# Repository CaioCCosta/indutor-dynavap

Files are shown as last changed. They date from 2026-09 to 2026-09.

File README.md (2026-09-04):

# Indutor DIY para Dynavap

**v1 fechada (set/2026).** Aquecedor de mesa **12 V 10 A** na tomada, caixa 3D pronta para imprimir (relevo AMS ou cavas + cola). Pack de 18650/21700 fica para uma **v2**.

Este kit junta o que Reddit (`r/inductionheaters`), FuckCombustion, VapOven, Thingiverse/Printables e aparelhos comerciais (Wand, YLL 3.0) acertam — e descarta o que queima módulo ou deixa o clique inconsistente.

| Documento | Conteúdo |
|---|---|
| [BOM e fiação](BOM_E_FIACAO.md) | Lista de peças no Brasil, pinos do Nano, diagrama |
| [**Caixa 3D v1**](caixa-3d/README.md) | [Lisa](caixa-3d/print/v1-lisa/), [relevo AMS](caixa-3d/print/v1/) ou [cavas](caixa-3d/print/v1-cavas/) |
| [Lista Mercado Livre](LISTA_COMPRAS_MERCADOLIVRE.md) | Buscas + anúncios + frete CEP 72120-250 |
| [Lista Shopee](LISTA_COMPRAS_SHOPEE.md) | Mesmo modelo de checklist na Shopee |
| [**Lista híbrida**](LISTA_COMPRAS_HIBRIDA.md) | **Melhor custo total — modelo, preço e frete por pedido** |
| [Firmware](firmware/indutor_dynavap.ino) | Botão, timeout 60 s, pulso lento, corte a 60 °C |
| [Afinação e segurança](AFINACAO_E_SEGURANCA.md) | Bobina 16 mm, alvo 60–70 W, checklist |
| [**Maquetes 3D**](maquetes/viewer.html) | Visualizador precisão v1.1 · [layout interno](maquetes/LAYOUT_INTERNO.md) · [montagem](maquetes/MONTAGEM.md) |

---

## Como funciona

O módulo **ZVS** (oscilador Royer, ~20–100 kHz) alimenta uma bobina. O campo magnético induz correntes de Foucault no cap de aço ou titânio; o metal esquenta de dentro para fora. O clique bimetálico continua sendo o termômetro. Vidro, cerâmica e plástico não aquecem.

O G3 de vidro **não** deve ir em indução (orientação DynaVap).

O que realmente muda o clique:

1. Diâmetro e número de espiras da bobina
2. Profundidade de inserção — o ponto mais quente é o **centro** da bobina
3. Potência efetiva — ~**60–70 W** dá extração uniforme; potência máxima deixa o clique rápido demais e inconsistente entre caps
4. Tempo de exposição — o IH não tem “temperatura”; ele só aquece enquanto estiver ligado

```mermaid
flowchart LR
  PSU["Fonte 12V 10A"] --> Fuse["Fusivel 10A"]
  Fuse --> MOSFET["MOSFET 15-30A"]
  MCU["Arduino Nano"] -->|"TRIG lento"| MOSFET
  MOSFET --> ZVS["Modulo ZVS 5-12V"]
  ZVS --> Coil["Bobina 16mm"]
  Coil --> Cap["Cap Dynavap"]
  Stop["Trava ajustavel"] --> Cap
```

---

## Comparação: comprar vs montar

### Aparelhos prontos

| Modelo | Tipo | Preço aprox. | O que acerta | O que falha |
|---|---|---|---|---|
| **Ispire Wand** | Portátil + dock | USD 115–180 | Adaptador Dynavap, auto/manual, 2×18650 | Auto-shutoff irregular; profundidade mal documentada; caro no BR |
| **YLL 3.0** | Portátil | USD 119–129 | **30–100 W**, profundidade ajustável, vidro trocável, timer 10–60 s, luz, 2×21700 | Baterias muitas vezes à parte; mais peça para copiar do que para reinventar |
| **VapOven** (pronto / kit) | Mesa ou bateria | £45–80 kit | Melhor documentação aberta; fonte de parede **12 V 10 A** | Frete UK; kit de bateria exige células high-drain |
| Orion / Portside Mini | Portátil clássico | nicho / descontinuado | Formato de bolso, clique previsível | Bateria única; variação de bobina entre unidades |
| Sense (Mad Heaters) | Portátil premium | alto | Corta no clique | Preço e estoque |
| Koil Boi / Caldron / VapHotBox / DynaBox | mesa ou USB-C | EUR 80–150 | “Liga e usa” | Menos ajuste que YLL; DIY ganha em custo |

**Comprar** Wand ou YLL 3.0 se a prioridade é usar amanhã. **Montar** este desktop se a prioridade é aprender e gastar ~R$ 150–280.

### Planos grátis e comunidade

| Fonte | O que pegar | O que não copiar |
|---|---|---|
| [VapOven library](https://vapoven.com/build-your-own-dynavap-induction-heater/) | MOSFET no positivo, não cortar o fio da bobina, Arduino com pulso e corte 60 °C | Lista antiga de fonte “12 V qualquer”; o produto deles usa **10 A** |
| [r/inductionheaters](https://www.reddit.com/r/inductionheaters/) + fiação jojo04201 | Arquitetura canônica: ZVS 5–12 V + MOSFET + botão momentâneo | LiPo de drone; comutar 10 A no botão barato |
| [jnico / Thingiverse](https://www.thingiverse.com/thing:4171627) | Caixa 3D, tubo de vidro, cortiça como trava | Fonte 6 A — justa demais |
| [acsdog / Printables](https://www.printables.com/model/1067938-dynavap-induction-heater-box-with-pwm) | Rebobinar 16 AWG no diâmetro do vidro, gabarito de enrolar | PWM de kHz no ZVS |
| [PULSE / Hackster](https://www.hackster.io/wiskey_tango_foxtrot/pulse-induction-heater-dc97ee) | Ciclos on/off de segundos (slowCook) | Tempos fixos no código; melhor um potenciómetro |
| FuckCombustion (física do IH) | Alvo **60–70 W**, banda quente no centro da bobina | Perseguir o clique mais rápido possível |

---

## Conflitos resolvidos

1. **Fonte 6 A vs 10 A.** O ZVS 120 W puxa ~10 A em 12 V. Fonte 6 A cai de tensão; abaixo de 12 V os dois MOSFETs do ZVS conduzem juntos e queimam. **Usar 12 V 10 A (folga: 12 A).**
2. **PWM no ZVS.** PWM de centenas de Hz / kHz impede o oscilador de arrancar. Potência = ligar/desligar o MOSFET em períodos de **100–500 ms**. Não usar `analogWrite` rápido.
3. **Bateria vs tomada.** 3S 18650 funciona, mas é o maior risco. LiPo de drone está fora. BMS de 10 A das listas antigas é apertado. **v1 na tomada.**
4. **Bobina de estoque vs rebobinada.** A bobina do módulo vem com ~23–28 mm de diâmetro interno — frouxa para o cap. Apertar sem cortar (~5 espiras / 16 mm) **ou** rebobinar 16 AWG, 8–10 espiras no tubo.
5. **Potência máxima vs sabor.** Clique < 3 s costuma super-extrair. FC recomenda 60–70 W para clique consistente entre caps.

---

## Arquitetura desta v1 (melhor de cada)

| Origem | O que entrou |
|---|---|
| VapOven | ZVS 5–12 V, MOSFET, botão momentâneo, LED na câmara, tubo 16 mm, O-ring, cavilha |
| YLL 3.0 | Potência ajustável, profundidade mecânica, **timeout 60 s**, vidro trocável, luz |
| FuckCombustion | Calibrar para ~60–70 W |
| Printables | Bobina justa no vidro |
| Thingiverse | Caixa 3D e trava de altura |
| Arduino VapOven | Pulso lento, corte térmico ~60 °C, LED de status |

**Fora da v1:** 18650/21700, BMS, LiPo, PWM de alta frequência, ZVS 12–48 V / 1800 W (é para fundir metal).

Firmware: botão pressionado aquece, soltou para; timeout 60 s se o botão travar; duty pelo potenciómetro; não dispara com dissipador ≥ 60 °C. O clique do cap é o feedback — não há malha IR nesta versão.

Próximo passo: imprimir uma das variantes em [`caixa-3d/print/`](caixa-3d/print/README.md), comprar pela [**lista híbrida**](LISTA_COMPRAS_HIBRIDA.md) (ou [ML](LISTA_COMPRAS_MERCADOLIVRE.md) / [Shopee](LISTA_COMPRAS_SHOPEE.md)), ligar conforme [BOM](BOM_E_FIACAO.md), gravar o [firmware](firmware/indutor_dynavap.ino), depois [afinar a bobina](AFINACAO_E_SEGURANCA.md).

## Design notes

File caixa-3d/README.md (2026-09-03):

# Caixa 3D — indutor Dynavap (A14) **v1 fechada**

**v1 fechada (set/2026).** OpenSCAD em `caixa-3d/`, [dimensions.json](../maquetes/dimensions.json) **v1.0** (92×58×65 mm + tampa 8 mm), ímã Ø12×3 em **X=−14**. Mesma caixa, **duas variantes oficiais** de acabamento tribal.

| Variante | Pasta | Uso |
|---|---|---|
| **Lisa** | [`print/v1-lisa/`](print/v1-lisa/) | Sem tribal; corpo + pads |
| **Relevo AMS** | [`print/v1/`](print/v1/) | Duas cores no Orca (Assemble) |
| **Cavas + cola** | [`print/v1-cavas/`](print/v1-cavas/) | Casca cavada 0,6 mm; inserts 0,5 mm colados |

Não misture os dois packs no mesmo Assemble.

## Arquivos — relevo AMS

Pasta: [`print/v1/`](print/v1/)

| Arquivo | O que é | Filamento Orca/Bambu AMS |
|---|---|---|
| [`corpo_cor1.stl`](print/v1/corpo_cor1.stl) | Casca do corpo + 4 pads | **1** PETG escuro |
| [`corpo_cor2.stl`](print/v1/corpo_cor2.stl) | Relevo tribal (5 faces) | **2** PETG claro |
| [`tampa_cor1.stl`](print/v1/tampa_cor1.stl) | Casca da tampa | **1** PETG escuro |
| [`tampa_cor2.stl`](print/v1/tampa_cor2.stl) | Relevo tribal do topo | **2** PETG claro |

Fallback **uma cor / lisa:** preferir [`print/v1-lisa/`](print/v1-lisa/) (`corpo_liso.stl` + `tampa_lisa.stl`). Alternativa unida com relevo: [`stl/box_body.stl`](stl/box_body.stl) · [`stl/box_lid.stl`](stl/box_lid.stl).

### OrcaSlicer / Bambu X1 Carbon

Imprima **corpo e tampa em placas separadas** (ou as duas na cama se couber).

1. **Add** `*_cor1.stl` e `*_cor2.stl` da mesma peça.
2. Selecione os dois → clique direito → **Assemble** (um objeto, duas partes).
3. Parte casca → **Filament 1**; parte relevo → **Filament 2**.
4. Perfil: **PETG**, camada **0,2 mm**, bico **0,4 mm**, infill **15–25 %**, sem suportes.
5. Orientação: corpo **piso no bed**; tampa **face plana no bed** (pocket, collarinho e relevo para cima).
6. O relevo tem **0,8 mm** = **4 camadas** de cor 2. Flush AMS no padrão.

Não use os STL unidos (`box_body.stl` / `box_lid.stl`) se quiser duas cores.

## Arquivos — cavas + cola

Pasta: [`print/v1-cavas/`](print/v1-cavas/) · [LEIA-ME](print/v1-cavas/LEIA-ME.md)

Cava **0,6 mm**; inserts **0,5 mm** deitados (`decais.stl` ou `decal_*.stl`). Imprime casca e tribal em placas **separadas** e cola.

## Gerar / regenerar STL

```powershell
cd caixa-3d
.\export.ps1
```

Pipeline: OpenSCAD gera `*_base.stl` → `assemble_embossed.py` gera `print/v1-lisa/`, `print/v1/` (AMS) e `print/v1-cavas/`.

Requer: [OpenSCAD](https://openscad.org/), Python com `trimesh`, `manifold3d`, `scikit-image`, `Pillow`.

| Arquivo | Função |
|---|---|
| `box_params.scad` | Medidas (corpo, furos, tubo, ímã, EMBOSS_H) |
| `box_body.scad` / `box_lid.scad` | Casca base imprimível |
| `box_emboss.scad` | Referência de layout do relevo (assembly em Python) |
| `decals/vectorize_decals.py` | JPG → STL de relevo 0,8 mm |
| `assemble_embossed.py` | Une base + decals (v1); difference cavas + inserts (`print/v1-cavas`) |
| `export.ps1` | Compila tudo |

## Decals tribais (alto relevo)

| Face | Decal | Arquivo |
|---|---|---|
| Laterais (frente, trás, esq., dir.) | **1** — asa horizontal | `decals/tribal_1_*` |
| Tampa (topo) | **2** — preenche a área livre (sem o bocal); ímã no centro | `decals/tribal_2_*` |
| Base (fundo) | **3** — chama no eixo longo | `decals/tribal_3_*` + **4 pads** 1,0 mm na casca (cor 1) |

- Altura do relevo: **0,8 mm** (`EMBOSS_H`)
- Keepouts: furos do painel, jack, fusível, vents, pocket ímã, collarinho, parafusos M3
- Regenerar só os relevos: `python decals/vectorize_decals.py` depois `python assemble_embossed.py`

### Cavidade do ímã

- Posição: **centro da área livre** da tampa (`X≈−14`), longe do tubo (`X≈28`)
- Pocket: **Ø12,6 × 3,2 mm** (ímã Ø12×3 + folga/cola)
- Fundo fechado — cola cianoacrilato ou epóxi 5 min
- Para ímã **12×6**: em `box_params.scad` defina `MAGNET_H = 6` e reexporte (gera boss local)

## Ímã de descanso (Dynavap upright)

Segura o M7 pelo cap metálico entre sessões. **Não** é a trava de profundidade do tubo (essa é o fundo de vidro).

| Exemplo | Spec | Nota | Link |
|---|---|---|---|
| VapOven Cooling Magnet | **12×3** N52 **diametral** (ou 12×6) | Referência Dynavap | [vapoven.com](https://vapoven.com/product/vapoven-cooling-magnet/) |
| DynaMag oficial | **12,6×1,5** diametral | Cabe no pocket com cola | [dynavap.com](https://www.dynavap.com/products/the-dynamag) |
| MadMag | **14×2** | Mais forte; mude `MAGNET_D=14` | [madheaters](https://madheaters.co.uk/products/madmag) |
| BR (axial) | **12×3 N35** ~1–2,5 kg tração ideal | Sobra p/ ~30 g do M7 | [Polo Magnético](https://www.polomagnetico.com.br/ima-de-neodimio/disco/ima-de-neodimio-12-x-3-mm-n35) · [Lorben](https://www.lorben.com.br/10-pecas-ima-neodimio-12x3mm-disco-pastilha-super-forte) |

**Preferir diametral** (cap centra e fica em pé). Axial funciona no peso, mas tombear é mais fácil. Não aqueça o ímã acima de **~80 °C**.

## Impressão sugerida (OrcaSlicer / X1 Carbon)

| Parâmetro | Valor |
|---|---|
| Material | **PETG** mínimo; **ASA/ABS** melhor perto do tubo |
| Camada | 0,2 mm |
| Preenchimento | 15–25 % |
| Corpo | Base no bed (Z=piso); pads 1 mm nos cantos (cor 1) |
| Tampa | Face plana no bed; pocket, collarinho e relevo para cima |
| Suportes | Desnecessário na cavidade ≤3,2 mm |
| Relevo tribal | Filamento **2**; nozzle **0,4 mm**; pontas finas podem arredondar |
| Parafusos | M3 nos 4 cantos (furos 3,4 mm; posts com piloto Ø2,4) |

## Encaixe com o BOM

Furos do painel (frente → traseira), alinhados à lista A5–A9 / A15:

| Item | Peça | Furo / rasgo |
|---|---|---|
| A7 | Gangorra redonda KCD1-106N | **Ø20,2 mm** |
| A5 | Pot B10K WH148 | **Ø7,6 mm** |
| A6 | Botão momentâneo 19 mm | **Ø19,2 mm** |
| A9 | LED 5 mm (×2) | **Ø5,2 mm** |
| A15 | Jack DC-022 P4 | **Ø8,2 mm** (traseira) |
| A8 | Porta-fusível 5×20 | **Ø13,2 mm** (traseira) |

- Tubo ensaio 16×42 (de 16×100) + cama cerâmica 24×24 sob o fundo
- Bobina + O-ring 15×3 no collarinho
- ZVS + MOSFET + Nano + pot + botão + rocker nos furos do painel
- Ventilação traseira 4×10×4 mm — não feche hermético
- Ímã colado na cavidade da tampa
- Fonte 12 V 10 A **fora** da caixa (só o jack entra)

## Alternativas (legado)

Se quiser partir de um design comunitário e editar:

- [acsdog — Printables](https://www.printables.com/model/1067938-dynavap-induction-heater-box-with-pwm) (domínio público, FreeCAD)
- [jnico — Thingiverse](https://www.thingiverse.com/thing:4171627)

A caixa paramétrica deste repo já inclui o layout v3.2 + ímã; prefira ela.

## Visualizar

[Viewer 3D](../maquetes/viewer.html) · [MONTAGEM.md](../maquetes/MONTAGEM.md)

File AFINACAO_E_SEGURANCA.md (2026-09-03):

# Afinação da bobina e segurança

Alvo desta v1: clique em **5–8 s** com **~60–70 W** (cerca de 5–6 A em 12 V com o cap inserido). Clique abaixo de 3 s costuma super-extrair; acima de 12 s a bobina está frouxa ou o duty está baixo demais.

Firmware e pinos: [indutor_dynavap.ino](firmware/indutor_dynavap.ino) e [BOM_E_FIACAO.md](BOM_E_FIACAO.md). Caixa oficial v1: [lisa](caixa-3d/print/v1-lisa/), [relevo](caixa-3d/print/v1/) ou [cavas](caixa-3d/print/v1-cavas/).

---

## Bobina: duas formas válidas

A bobina de fábrica do ZVS 120 W vem com ~23–28 mm de diâmetro interno. O cap Dynavap fica longe do cobre e o clique atrasa ou fica irregular. **Não corte o fio** se for só remodelar o comprimento original — o tanque LC precisa dessa indutância.

### A) Apertar a bobina original (VapOven)

1. Use o tubo de 16 mm como mandril.
2. Feche para **~5 espiras** justas no vidro.
3. O restante do fio fica dobrado para o lado, **inteiro**, até os bornes.
4. Soldar a bobina na placa. Bornes de plástico derretem com o uso.

### B) Rebobinar 16 AWG (Printables / acsdog)

1. Fio esmaltado 16 AWG. Raspé as pontas até o cobre aparecer.
2. Enrolar **8–10 espiras** no tubo de 16 mm (ou num gabarito do mesmo diâmetro).
3. Espiras apertadas, sem sobrepor isolamento danificado (curto entre voltas mata o ZVS).
4. Mesmo número de voltas da bobina original se você medi-las antes de desmontar — ponto de partida mais seguro.
5. Soldar na placa.

O tubo de vidro fica **dentro** da bobina. O-ring 15×3 mm fixa o tubo na caixa. O **fundo fechado** do tubo (ensaio 16×100 cortado) é o stop do cap. A cama cerâmica 24×24 fica **sob** o fundo (isola PETG). O ímã Ø12×3 na **tampa** é só descanso upright — não define profundidade.

---

## Profundidade (YLL + FuckCombustion)

O campo é uma banda quente no **centro** das espiras. Mais cap dentro da bobina = mais cobre “vendo” metal = clique mais rápido.

| Objetivo | Ajuste |
|---|---|
| Primeiro teste | Cap **inteiro** na bobina |
| Clique < 3 s | Menos cap no centro / abrir espiras / baixar pot |
| Clique > 12 s | Mais cap na bobina / apertar espiras / subir pot |
| Sabor / terpenos | Um pouco menos fundo, duty menor (pulso) |
| Nuvem | Cap inteiro, duty alto, ainda na faixa 60–70 W |

Marque a posição boa com uma fita no tubo. A repetibilidade é o motivo de existir IH.

---

## Procedimento de afinação

Faça com a caixa aberta, multímetro em série no positivo (escala 10 A DC) se possível, e o interruptor geral à mão.

1. **Bobina no ar, sem cap.** Pulso curto. Corrente ociosa baixa (cerca de 1–2 A nos ZVS bem comportados). Fonte não pode piscar nem cair abaixo de ~11,5 V.
2. **Pot no mínimo** (sentido do sketch = potência cheia). Inserir o Dynavap até o fundo do tubo. Contar até o clique.
3. Alvo **5–8 s**. Anotar corrente com o cap dentro.
4. Potência elétrica ≈ `12 V × corrente`. Ajustar pot e/ou bobina para **~5–6 A (60–72 W)**. Não persiga o 10 A nominais do módulo.
5. Se a fonte entrar em proteção: espiras demais / diâmetro pequeno demais / cap enfiado demais. Abra a bobina ou reduza a penetração do cap.
6. Se o clique não vem: cap de vidro/cerâmica, bobina frouxa, polaridade do MOSFET, ou TRIG invertido (`MOSFET_ACTIVE_HIGH`).
7. Com o TMP36 no dissipador, segure o botão: em ≥ 60 °C o LED status pisca rápido e o ZVS corta. Solte e espere cair de 55 °C. Serial `Ts=0` significa sensor ausente ou leitura absurda — o corte térmico fica desligado até o TMP36 estar no dissipador.
8. Segure 60 s de propósito: o firmware corta (pisca lento). Solte o botão para rearmar.

Módulos ZVS nacionais pedem pausa depois de ~5 min contínuos. O timeout de 60 s cobre o uso real; não use o IH como fogão.

---

## Potenciómetro no firmware

| Posição | Comportamento |
|---|---|
| Quase todo aberto (ADC baixo) | ZVS contínuo enquanto o botão estiver apertado |
| Meio / fechado | Pulso lento, período 500 ms, “on” de ~500 ms até 120 ms |

Isso é o slowCook do VapOven / PULSE do Hackster: o ZVS **arranca e oscila** em cada pulso. PWM de kHz não dá tempo de oscilar e queima MOSFET.

---

## Checklist de segurança

Faça na ordem. Qualquer “não” = não aquece o cap.

- [ ] Fonte é **12 V 10 A** (ou 12 A), não 6 A
- [ ] ZVS é o de **5–12 V / 120 W**, não o de 1800 W
- [ ] Fusível **10 A** no positivo, depois do interruptor, antes do MOSFET
- [ ] MOSFET comuta o **12 V do ZVS**; botão só no D2
- [ ] GND comum: fonte, MOSFET, ZVS, Nano
- [ ] Polaridade da fonte conferida no jack
- [ ] Bobina soldada; isolamento entre espiras intacto; **fio original não cortado** se for o método A
- [ ] Dissipadores do ZVS com ar; caixa não é fechada hermética
- [ ] TMP36 no dissipador, não flutuando no ar da caixa
- [ ] Timeout e corte térmico testados **sem** cap na primeira vez
- [ ] Não usar Dynavap **G3 de vidro** (nem cap de vidro/cerâmica/plástico)
- [ ] Cap sai quente; o vidro isola a **bobina**, não o cap
- [ ] Não deixar o botão preso e sair da sala — o timeout é backup, não babysitter
- [ ] Sem LiPo. v2 de bateria: só 18650/21700 high-drain ≥ 20 A e BMS ≥ 15 A

---

## Sintomas comuns

| Sintoma | Causa mais provável |
|---|---|
| Fonte pisca / desliga | Bobina curta, diâmetro pequeno demais, fonte < 10 A |
| MOSFETs do ZVS queimam na hora | Tensão < 12 V, ZVS não oscilou, PWM rápido no TRIG |
| Clique instantâneo | Bobina apertada demais ou cap no centro; subir trava |
| Demora demais | Bobina de estoque larga; reenrolar ou apertar |
| LED status pisca rápido | Corte térmico 60 °C |
| LED status pisca lento com botão preso | Timeout 60 s — solte o botão |
| Nada aquece, Serial `zvs=0` com `btn=1` | `lock=1`, `to=1`, ou TRIG invertido |
| Nano reseta quando o ZVS liga | Fios de potência longos / GND ruim — encurtar e estreitar o loop |

---

## v2 (não misturar com a primeira solda)

Só depois que a v1 clicar estável em 5–8 s:

- 3S 18650 **ou** 2S 21700 high-drain (≥ 20 A contínuos)
- BMS ≥ 15 A, holder rígido, indicador de carga
- **Nunca LiPo** de drone
- Carregar com fonte 12,6 V adequada ao pack, ou USB-C num módulo de carga decente

Até lá, a tomada é o modo mais seguro e o que o VapOven comercial usa em 12 V 10 A.

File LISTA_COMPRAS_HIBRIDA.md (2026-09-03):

# Lista híbrida — 2 pacotes com links (CEP 72120-250)

Estratégia: **no máximo 2 fretes**. Links abaixo abrem o anúncio ou uma busca já filtrada — confira **foto + descrição** antes de pagar.

| Lista | Uso |
|---|---|
| [Shopee](LISTA_COMPRAS_SHOPEE.md) | Detalhe item a item |
| [Mercado Livre](LISTA_COMPRAS_MERCADOLIVRE.md) | Detalhe item a item |
| **Esta (híbrida)** | **Comprar — links + como reconhecer** |

---

## Como usar esta lista

1. Informe o CEP **72120-250** na conta (Shopee e ML).
2. Clique no **link principal** do item.
3. Confira a coluna **Como reconhecer** — é o filtro real quando o título mente.
4. **Pacote A:** adicione tudo na **mesma loja** Shopee antes de pagar.
5. **Pacote B:** prefira filtro **Full** + **frete grátis** no ML.
6. Links de anúncio podem sumir; use o **texto para buscar** como fallback.

**Legenda dos links**

| Tipo | Significado |
|---|---|
| **Anúncio** | URL direta de produto (preferir) |
| **Busca** | Resultado filtrado — abra os 3 primeiros e compare |
| **Loja** | Fallback nacional com spec confirmada (3º frete) |

---

## Resumo — 2 pacotes

| Pacote | Onde | Itens | Produto est. | Frete est. | Total est. |
|---|---|---|---|---|---|
| **A** | Shopee (1 loja) | ZVS + eletrônica + passivos + fios + O-ring (**caixa = 3D grátis**) | R$ 115–145 | R$ 0–10 | **R$ 115–155** |
| **B** | ML Full | Fonte 12 V 10 A + manga de vidro Ø16 mm (se ainda não tiver) | R$ 22–63 | **R$ 0** | **R$ 22–63** |
| | | | | **Total** | **~R$ 140–185** (menos se pular B2) |

---

# Pacote A — Shopee (1 frete)

**Entrada na loja:** abra um item abaixo → clique no **nome da loja** → adicione os demais itens A2–A15 **no mesmo vendedor**.

**Busca ampla (se preferir escolher loja):** [arduino nano mosfet zvs](https://shopee.com.br/search?keyword=arduino%20nano%20mosfet%20zvs)

---

## Status do carrinho (atualizado)

| # | Item | Status | Link / nota |
|---|---|---|---|
| A1 | ZVS 5–12 V 120 W + bobina | **OK** | [Código 1140](https://shopee.com.br/M%C3%B3dulo-Driver-Zvs-5v-12v-Zvs-Aquecedor-Por-Indu%C3%A7%C3%A3o-C%C3%B3digo-1140--i.362820645.22798008676) — ignore “1–2 A” na descrição; @12 V puxa ~10 A |
| A2 | MOSFET XY-MOS 15 A 400 W | **OK** | [XY-MOS](https://shopee.com.br/M%C3%B3dulo-Driver-Para-Pwm-5v-36v-15a-400w-Xy-mos-i.436232821.9753969774) |
| A3 | Nano V3 ATmega328 + cabo | **OK** | [Nano](https://shopee.com.br/Placa-Nano-V3-Atmega328-Pinos-Soldados-Cabo-Para-Arduino-i.564186623.21397793828) |
| A4 | TMP36 TO-92 | **OK** | [TMP36](https://shopee.com.br/Sensor-De-Temperatura-Tmp36-To92-C%C3%B3digo-1025--i.362820645.11885701058) |
| A5 | Pot B10K | **via kit** | Furo **Ø7,6** — [Kit Uno Starter](https://shopee.com.br/Kit-Arduino-Uno-Starter-(Compativel)-com-Protoboard-e-Componentes-Eletronicos-para-Iniciante-Eletronica-Robotica-i.413370384.14291335771) |
| A6 | Botão momentâneo | **OK*** | [Pulso 19 mm](https://shopee.com.br/Bot%C3%A3o-Pulso-Moment%C3%A2neo-19mm-Led-12v-24v-i.371650678.21953103073) — furo **Ø19,2**; só contatos (LED 12/24 V) |
| A7 | Gangorra redonda LED | **OK** | [KCD1-106N](https://shopee.com.br/Kit-Chaves-Gangorra-Com-Led-3-Polos-KCD1-6a-250v-10a-127-i.1215439885.19798144413) — furo **Ø20,2**; LED interno pode não acender em 12 V DC |
| A8 | Fusível 10 A + suporte | **OK** | [Porta 5×20 + 10 A](https://shopee.com.br/2-KIT-PORTA-FUS%C3%8DVEL-5x20-FUSIVEIS-10A-i.401537788.58211270973) — furo traseiro **Ø13,2** |
| A9 | LED + resistor 5 V | **via kit** | No kit starter; se faltar, LED + resistor **5 V** |
| A10 | Fio 16 AWG silicone | **OK*** | [Fio siliconado](https://shopee.com.br/Fio-siliconado-8awg-10awg-12awg-14awg-16awg-18awg-20awg-50cm-vermelho-e-preto-bateria-lipo-drone-aeromodelo-silicone-i.388403980.8071601504) — no dropdown escolha **16 AWG** (não 8/10) |
| A11 | Jumpers | **via kit** | Kit starter |
| A12 | O-ring 15×3 | **OK*** | [Jogo 225 anéis](https://shopee.com.br/JOGO-COM-225-ANEIS-DE-VEDACAO-DE-BORRACHA-O-RING-18-TAMANHOS-i.531578878.23893983854) — confira se inclui **15×3** |
| A13 | Cama cerâmica 24×24 mm | **OK** | [Roldana isolador chocadeira](https://shopee.com.br/KIT-4-Roldanas-Isolador-Cer%C3%A2mico-24-X-24-Mm-Chocadeira-i.536455119.12843383768) — sob o fundo do tubo |
| A14 | Caixa | **3D v1** | [Lisa](caixa-3d/print/v1-lisa/), [relevo](caixa-3d/print/v1/) ou [cavas](caixa-3d/print/v1-cavas/) — [guia](caixa-3d/README.md) |
| A15 | Jack P4 5,5×2,1 | **OK** | [Jack fêmea](https://shopee.com.br/Conector-Plug-Jack-Tipo-P4-Dc-Femea-Dc-022-2-1x5-5mm-01UN-i.778214063.18697736011) — furo **Ø8,2** |
| A16 | Ímã descanso Ø12×3 | **comprar** | Disco neodímio p/ Dynavap upright na tampa — ver A16 |

**Ainda falta (Pacote B):** fonte **12 V 10 A** · tubo de ensaio **16×100** (vidro comum, fundo fechado — ver B2) · ímã A16.  
**Atenção frete:** vários vendedores = vários fretes; se o total de frete passar ~R$ 25–30, vale juntar o que der na mesma loja.

---

## A1 — ZVS 5–12 V 120 W + bobina

| Campo | Valor |
|---|---|
| **Texto para buscar** | `5V-12V ZVS 120W bobina` ou `ZVS Mini Indução 120W` |
| **Códigos/SKUs** | MA712 · HW-838 · WP6-J6 |
| **Preço est.** | R$ 36–55 |

**Como reconhecer (certo)**

- Título diz **5V–12V** (ou 5–12 V DC) e **120W** (ou ~120 W)
- Foto mostra **bobina de cobre enrolada** inclusa
- Placa pequena (~5,5 × 4 cm), 2 MOSFETs com dissipador, **sem** ventoinha gigante
- Descrição: corrente ~**10 A @ 12 V**

**Evitar**

- 1000 W / 1800 W / 2500 W
- 12–48 V ou “fundição de metal”
- Só placa, sem bobina na foto

| Link | Tipo |
|---|---|
| [Lista Shopee — Aquecedor Indução](https://shopee.com.br/list/Aquecedor/Indu%C3%A7%C3%A3o) | **Busca** — itens #1 e #2 costumam ser o modelo certo (~R$ 36–44) |
| [Busca: 5V-12V ZVS 120W bobina](https://shopee.com.br/search?keyword=5v-12v%20zvs%20120w%20bobina) | Busca |
| [Busca alt.: módulo ZVS aquecimento indução](https://shopee.com.br/search?keyword=modulo%20zvs%20aquecimento%20inducao) | Busca |
| [Smart Kits MA712 — R$ 49,90](https://www.smartkits.com.br/modulo-aquecedor-indutivo-5v-a-12v) | Loja (3º frete) |

- [ ] A1 comprado

---

## A2 — MOSFET 15 A / 400 W (XY-MOS / D4184)

| Campo | Valor |
|---|---|
| **Texto para buscar** | `módulo mosfet pwm 15A 400W D4184` |
| **Códigos** | XY-MOS · D4184 · D4184A · AOD4184 |
| **Preço est.** | R$ 9–16 |

**Como reconhecer (certo)**

- Placa retangular ~3,4 × 1,7 cm com **3 bornes de parafuso** (Vin+, Vin−, Vout−) + pino **TRIG/PWM**
- Título ou descrição: **15 A** e **400 W** (ou 5–36 V, PWM 3,3–20 V)
- Foto: **dois MOSFETs** em paralelo (não um chip IRF520 sozinho)

**Evitar**

- “IRF520 driver” mini (5 A — fraco para 10 A do ZVS)
- Módulo só com pinos header, sem bornes (menos seguro em 10 A)

| Link | Tipo |
|---|---|
| [Busca: mosfet pwm 15A 400W](https://shopee.com.br/search?keyword=mosfet%20pwm%2015a%20400w) | **Busca** |
| [Busca: XY-MOS D4184](https://shopee.com.br/search?keyword=xy-mos%20d4184) | Busca |
| [MLB-1565523372 — driver 25 A (serve)](https://produto.mercadolivre.com.br/MLB-1565523372-modulo-driver-mosfet-25a-para-mesa-aquecida-impressoras-3d-_JM) | Anúncio ML (se comprar no B) |
| [Saravati 15A 400W — R$ 6,90](https://www.saravati.com.br/modulo-controlador-pwm-n-mos-mosfet-5v-a-36v-15a-400w.html) | Loja (3º frete) |

- [ ] A2 comprado

---

## A3 — Arduino Nano V3 ATmega328 CH340 + cabo USB

| Campo | Valor |
|---|---|
| **Texto para buscar** | `Arduino Nano V3 ATmega328 CH340 cabo` |
| **Preço est.** | R$ 20–42 |

**Como reconhecer (certo)**

- **Nano** (não Uno/Mega) — placa ~4,5 × 1,8 cm
- Chip **ATmega328** (ou ATmega328P) + conversor **CH340** (ou CH340G)
- Versão com **cabo USB** (mini-USB, micro-USB ou USB-C — qualquer serve)
- 5V, 16 MHz, 14 digitais / 8 analógicos

**Evitar**

- Nano **Every** / **R4** (firmware deste projeto é para ATmega328)
- “Nano” sem especificar 328 — pode ser RP2040 etc.

| Link | Tipo |
|---|---|
| [Busca: nano v3 atmega328 ch340 cabo](https://shopee.com.br/search?keyword=arduino%20nano%20v3%20atmega328%20ch340%20cabo) | **Busca** |
| [Anúncio: Nano compatível (loja 413370384)](https://shopee.com.br/Uno-ou-NANO-(Arduino-Compat%C3%ADveis)-i.413370384.19140344857) | Anúncio — escolher variante **Nano** no dropdown |
| [MakerHero Nano + cabo](https://www.makerhero.com/produto/placa-nano-v3-0-cabo-usb-para-arduino/) | Loja (3º frete) |

- [ ] A3 comprado

---

## A4 — Sensor TMP36 TO-92

| Campo | Valor |
|---|---|
| **Texto para buscar** | `sensor temperatura TMP36 TO-92` |
| **Preço est.** | R$ 8–18 |

**Como reconhecer (certo)**

- CI de **3 pinos** formato **TO-92** (parece transistor)
- Marcação no corpo: **TMP36** (não LM35, não NTC)
- Descrição: saída **10 mV/°C**, faixa −40 a +125 °C, alimentação 2,7–5,5 V

**Evitar**

- DS18B20 (digital, 1 fio — não serve sem mudar firmware)
- LM35 (escala diferente)
- “Módulo” com placa azul — quer o **sensor nu** TO-92

| Link | Tipo |
|---|---|
| [Busca: TMP36 sensor temperatura](https://shopee.com.br/search?keyword=tmp36%20sensor%20temperatura) | **Busca** |
| [Cinestec TMP36 — R$ 13,50](https://www.cinestec.com.br/tmp36-to-92-sensor-temperatura) | Loja (3º frete) |

- [ ] A4 comprado

---

## A5 — Potenciômetro B10K linear

| Campo | Valor |
|---|---|
| **Texto para buscar** | `potenciometro 10k linear B10K` |
| **Preço est.** | R$ 3–8 |
| **Furo no painel** | **Ø7,6 mm** (bushing WH148 ~Ø7,2–7,5 + folga print) |

**Como reconhecer:** rosca **B10K** ou **10K linear** (não logarítmico A10K). Eixo 6 mm se for no painel. Corpo atrás do painel ~Ø16–17 mm — o furo é só a rosca, não o corpo.

| Link | Tipo |
|---|---|
| [Busca: potenciometro 10k linear](https://shopee.com.br/search?keyword=potenciometro%2010k%20linear) | **Busca** |

- [ ] A5 comprado

---

## A6 — Botão momentâneo SPST

| Campo | Valor |
|---|---|
| **Texto para buscar** | `botao momentaneo painel 19mm` |
| **Preço est.** | R$ 3–10 |
| **Furo no painel** | **Ø19,2 mm** (nominal 19 mm + 0,2 print); cabeça típ. Ø22 |
| **Escolhido** | [Pulso 19 mm LED 12/24 V](https://shopee.com.br/Bot%C3%A3o-Pulso-Moment%C3%A2neo-19mm-Led-12v-24v-i.371650678.21953103073) |

**Como reconhecer:** **momentâneo** (volta ao soltar). Não comprar botão **toggle/trava**. Use só os contatos SPST; LED interno é 12/24 V (ignore ou alimente do 12 V).

| Link | Tipo |
|---|---|
| [Anúncio 19 mm (escolhido)](https://shopee.com.br/Bot%C3%A3o-Pulso-Moment%C3%A2neo-19mm-Led-12v-24v-i.371650678.21953103073) | **Anúncio** |
| [Busca: botao momentaneo 19mm](https://shopee.com.br/search?keyword=botao%20momentaneo%20painel%2019mm) | Busca |

- [ ] A6 comprado

---

## A7 — Chave gangorra redonda KCD1-106N ≥ 6 A

| Campo | Valor |
|---|---|
| **Texto para buscar** | `chave gangorra redonda led 20mm KCD1` |
| **Preço est.** | R$ 3–8 |
| **Furo no painel** | **Ø20,2 mm** (nominal 20 mm + 0,2 print) |
| **Escolhido** | [Gangorra LED 3 polos](https://shopee.com.br/Kit-Chaves-Gangorra-Com-Led-3-Polos-KCD1-6a-250v-10a-127-i.1215439885.19798144413) |

**Como reconhecer:** **redonda** (~Ø20 mm), 3 polos, rating **≥ 6 A**. O neon/LED do kit costuma ser **127/220 V AC** e **não acende em 12 V DC** — use os contatos ON/OFF; o LED interno pode ficar apagado.

| Link | Tipo |
|---|---|
| [Anúncio (escolhido)](https://shopee.com.br/Kit-Chaves-Gangorra-Com-Led-3-Polos-KCD1-6a-250v-10a-127-i.1215439885.19798144413) | **Anúncio** |
| [Busca: chave gangorra redonda led](https://shopee.com.br/search?keyword=chave%20gangorra%20redonda%20led) | Busca |

- [ ] A7 comprado

---

## A8 — Fusível 10 A + suporte painel 5×20

| Campo | Valor |
|---|---|
| **Texto para buscar** | `porta fusivel 5x20 painel 10A` |
| **Preço est.** | R$ 5–12 |
| **Furo traseiro** | **Ø13,2 mm** (painel 5×20 típ. Ø12–13) |
| **Escolhido** | [2-KIT porta-fusível 5×20 + 10 A](https://shopee.com.br/2-KIT-PORTA-FUS%C3%8DVEL-5x20-FUSIVEIS-10A-i.401537788.58211270973) |

**Como reconhecer:** fusível **vidro 5×20 mm 10 A** + suporte **de painel** (tampa rosqueável). Vai no **positivo** logo após o jack, na **traseira** da caixa.

| Link | Tipo |
|---|---|
| [Anúncio (escolhido)](https://shopee.com.br/2-KIT-PORTA-FUS%C3%8DVEL-5x20-FUSIVEIS-10A-i.401537788.58211270973) | **Anúncio** |
| [Busca: porta fusivel 5x20 painel](https://shopee.com.br/search?keyword=porta%20fusivel%205x20%20painel) | Busca |

- [ ] A8 comprado

---

## A9 — LED 5 mm + resistor (×2)

| Campo | Valor |
|---|---|
| **Texto para buscar** | `kit led 5mm resistor` ou `LED 5mm 5V` |
| **Preço est.** | R$ 3–8 |
| **Furo no painel** | **Ø5,2 mm** (2×) |

Os LEDs ligam nos pinos **D5/D6 do Nano (5 V)**. Se a loja só oferecer opção por tensão (**5 V / 9 V / 12 V / 24 V**), escolha **5 V** — isso é o resistor certo para Arduino. **Não** pegue 12 V/24 V (LED fica apagado ou fraco demais neste circuito).

Se a loja mostrar ohms: **220–470 Ω** ¼ W. Precisa de **2 LEDs 5 mm** + **2 resistores**.

| Link | Tipo |
|---|---|
| [Busca: led 5mm kit resistor](https://shopee.com.br/search?keyword=led%205mm%20kit%20resistor) | **Busca** |
| [Busca: led 5mm 5v](https://shopee.com.br/search?keyword=led%205mm%205v%20resistor) | Busca (variante por tensão) |

- [ ] A9 comprado

---

## A10 — Fio potência 16 AWG silicone (~1 m)

| Campo | Valor |
|---|---|
| **Texto para buscar** | `fio silicone 16 awg vermelho preto` |
| **Preço est.** | R$ 6–12 |

**Como reconhecer:** **16 AWG** (ou 1,5 mm²), silicone, vermelho + preto, ~0,5–1 m cada cor.

| Link | Tipo |
|---|---|
| [Busca: fio silicone 16 awg](https://shopee.com.br/search?keyword=fio%20silicone%2016%20awg) | **Busca** |

- [ ] A10 comprado

---

## A11 — Fio sinal (jumper macho-fêmea)

| Campo | Valor |
|---|---|
| **Texto para buscar** | `fio jumper arduino macho femea` |
| **Preço est.** | R$ 5–10 |

| Link | Tipo |
|---|---|
| [Busca: fio jumper arduino](https://shopee.com.br/search?keyword=fio%20jumper%20arduino) | **Busca** |

- [ ] A11 comprado

---

## A12 — O-ring 15 × 3 mm

| Campo | Valor |
|---|---|
| **Texto para buscar** | `o-ring 15x3` ou `anel borracha 15mm 3mm` |
| **Preço est.** | R$ 4–8 |

**Como reconhecer:** **OD 15 mm × espessura 3 mm** (nitrila). Pacote com várias unidades.

| Link | Tipo |
|---|---|
| [Busca: o-ring 15x3](https://shopee.com.br/search?keyword=o-ring%2015x3) | **Busca** |

- [ ] A12 comprado

---

## A13 — Cama cerâmica 24×24 mm (escolhida)

**Não vai dentro do tubo.** Fica **embaixo** do fundo fechado do tubo de ensaio: aparador térmico entre o vidro quente e a base PETG.

| Campo | Valor |
|---|---|
| **Peça** | Roldana / isolador cerâmico **24 × 24 mm** (chocadeira) |
| **Ø externo** | **24 mm** (maior que o tubo OD 16 mm — correto para “cama”) |
| **Furo central** | ~**5 mm** (opcional: parafuso nylon/plástico; nunca metal perto da bobina) |
| **Material** | Porcelana esmaltada — não aquece por indução |
| **Preço est.** | R$ 10–20 (kit com 4; use 1) |

**Função no projeto**

| Quem faz o quê | Peça |
|---|---|
| Para o cap do M7 | **Fundo fechado do tubo** (vidro) |
| Isola a caixa do calor | **Cerâmica 24×24 sob o tubo** |

Montar **abaixo da bobina**, só sob o fundo do tubo. Se subir demais, a roldana 24 mm bate na coil (OD ~22 mm).

| Link | Tipo |
|---|---|
| [KIT 4 roldanas isolador 24×24 mm chocadeira](https://shopee.com.br/KIT-4-Roldanas-Isolador-Cer%C3%A2mico-24-X-24-Mm-Chocadeira-i.536455119.12843383768) | **Anúncio (escolhido)** |

- [x] A13 definido (24×24 mm sob o tubo)

---

## A14 — Caixa 3D v1 (não comprar ABS)

| Campo | Valor |
|---|---|
| **Projeto** | OpenSCAD neste repo — 92×58×65 + tampa 8 + ímã X=−14 |
| **Imprimir** | [Lisa](caixa-3d/print/v1-lisa/), [relevo AMS](caixa-3d/print/v1/) **ou** [cavas](caixa-3d/print/v1-cavas/) |
| **Uma cor (união)** | Fallback [`box_body.stl`](caixa-3d/stl/box_body.stl) · [`box_lid.stl`](caixa-3d/stl/box_lid.stl) |
| **Preço** | **R$ 0** (imprimir PETG/ASA) |
| **Guia** | [caixa-3d/README.md](caixa-3d/README.md) · [packs](caixa-3d/print/README.md) |
| **Export** | `.\caixa-3d\export.ps1` (OpenSCAD) |

**Não compre** caixa ABS pronta se for imprimir. Legado opcional: [acsdog](https://www.printables.com/model/1067938-dynavap-induction-heater-box-with-pwm) / [jnico](https://www.thingiverse.com/thing:4171627).

- [ ] A14 impresso (nossa caixa)

---

## A15 — (Opc.) Jack DC 5,5 × 2,1 mm fêmea

Só se a fonte do Pacote B tiver **plug P4** em vez de bornes.

| Campo | Valor |
|---|---|
| **Escolhido** | [Jack fêmea DC-022 2,1×5,5](https://shopee.com.br/Conector-Plug-Jack-Tipo-P4-Dc-Femea-Dc-022-2-1x5-5mm-01UN-i.778214063.18697736011) |
| **Furo traseiro** | **Ø8,2 mm** (rosca típ. Ø8 + folga print) |

| Link | Tipo |
|---|---|
| [Anúncio DC-022 (escolhido)](https://shopee.com.br/Conector-Plug-Jack-Tipo-P4-Dc-Femea-Dc-022-2-1x5-5mm-01UN-i.778214063.18697736011) | **Anúncio** |
| [Busca: jack dc 5.5 2.1 femea](https://shopee.com.br/search?keyword=jack%20dc%205.5%202.1%20femea) | Busca |

- [ ] A15 comprado (ou dispensado)

---

## A16 — Ímã de descanso Ø12×3 mm (tampa)

Cola na **cavidade** do topo esquerdo da tampa. Segura o Dynavap **em pé** pelo cap entre sessões. Preferir **magnetização diametral**.

| Exemplo | Spec | Força / uso | Link |
|---|---|---|---|
| VapOven Cooling Magnet | 12×3 N52 **diametral** (ou 12×6) | Feito p/ Dynavap | [vapoven.com](https://vapoven.com/product/vapoven-cooling-magnet/) |
| DynaMag | 12,6×1,5 diametral | Compacto; cabe no pocket | [dynavap.com](https://www.dynavap.com/products/the-dynamag) |
| MadMag | 14×2 | Mais forte (decap); mude `MAGNET_D` | [madheaters](https://madheaters.co.uk/products/madmag) |
| BR axial (fácil) | **12×3 N35** | ~1–2,5 kg tração ideal — sobra p/ M7 (~30 g) | [Polo Magnético](https://www.polomagnetico.com.br/ima-de-neodimio/disco/ima-de-neodimio-12-x-3-mm-n35) · [Lorben 10un](https://www.lorben.com.br/10-pecas-ima-neodimio-12x3mm-disco-pastilha-super-forte) |

Cola: Super Bonder ou epóxi 5 min. Não exceda ~80 °C no ímã.

- [ ] A16 comprado (12×3; diametral se achar)

---

### Checklist Pacote A (antes de pagar)

- [ ] Itens A1–A12/A15 na **mesma loja** Shopee quando possível (A13 já escolhido: roldana 24×24)
- [ ] ZVS = **5–12 V / 120 W** com **bobina na foto**
- [ ] MOSFET = **15 A 400 W** com **bornes** (não IRF520 mini)
- [ ] Nano = **V3 ATmega328 CH340**
- [ ] TMP36 = **TO-92** (sensor nu)
- [ ] Frete grátis ou cupom aplicado

- [ ] **Pacote A comprado**

---

# Pacote B — Mercado Livre Full (frete R$ 0)

Filtro sugerido: [Full + frete grátis](https://lista.mercadolivre.com.br/_CostoEnvio_Gratis_Frete_Full_NoIndex_True) — informe CEP `72120-250`.

---

## B1 — Fonte 12 V 10 A 120 W (colmeia ou box)

| Campo | Valor |
|---|---|
| **Texto para buscar** | `fonte chaveada 12V 10A 120W colmeia bivolt` |
| **Preço est.** | R$ 22–40 |

**Como reconhecer (certo)**

- Saída **12 V DC**, corrente **10 A** (ou 120 W)
- Bivolt 110/220 V
- Bornes de parafuso (colmeia) **ou** plug 5,5×2,1 mm (box)
- Foto: carcaça metálica perfurada **ou** caixa compacta — não “fonte 1 A”

**Evitar**

- 5 A / 6 A
- “10 A” a R$ 12 sem reputação (mentem amperagem)

| Link | Tipo |
|---|---|
| [MLB-3179848283 — colmeia 12V 10A Full ~R$ 37](https://produto.mercadolivre.com.br/MLB-3179848283-fonte-bivolt-estabilizada-colmeia-12v-10a-120w-led-cmera-ch-_JM) | **Anúncio** |
| [MLB-1080684277 — colmeia 12V 10A ~R$ 37](https://produto.mercadolivre.com.br/MLB-1080684277-fonte-para-dvr-chaveada-12v-10a-tipo-colmeia-ideal-para-cftv-_JM) | Anúncio |
| [Catálogo MLB44562202 — fonte 12V 10A 120W](https://www.mercadolivre.com.br/fonte-chaveada-12v-10a-120w-mgc-colmeia-cftv-cmera-seguranca-aluminio/p/MLB44562202) | Catálogo |
| [Busca Full: fonte 12V 10A](https://lista.mercadolivre.com.br/fonte-chaveada-12v-10a_Frete_Full_NoIndex_True) | Busca |

- [ ] B1 comprado

---

## B2 — Tubo de ensaio Ø16 mm, fundo fechado (v1 reformulada)

**Decisão:** borossilicato fino Ø15–16 mm sumiu do varejo fácil (Cloutank M3 legado; VaptBR 16×2,5 mm é grosso demais). **v1 usa tubo de ensaio de vidro comum 16×100 ou 16×150**, fundo fechado.

| Campo | Valor |
|---|---|
| **Tamanho no dropdown** | **16×100** ou **16×150** (Ø 16 mm × comprimento) |
| **Fundo** | **Fechado** — é a trava do cap |
| **Material** | Vidro comum / neutro (aceitável na v1) |
| **Uso** | Corte em **~40–50 mm**, **mantenha o fundo** |
| **Preço est.** | R$ 3–15 |

**Por que vidro comum serve aqui**

| Fato | Efeito |
|---|---|
| Vidro **não** aquece por indução | Só esquenta por **contato** com o cap (~5–8 s) |
| Fundo fechado | Cap para no vidro; não precisa insert interno |
| Cama A13 24×24 sob o tubo | Isola PETG do fundo quente |
| Timeout 60 s + TMP36 | Limita aquecimento prolongado |

**Risco residual:** choque térmico (trinca) maior que borossilicato. Sessões curtas; se trincar, troca o tubo (barato).

**Como reconhecer (certo)**

| Spec | Valor |
|---|---|
| Ø externo | **16 mm** |
| Comprimento comprado | 100 ou 150 mm |
| Comprimento no projeto | ~40–50 mm (fundo intacto) |
| ID típico | ~13–14 mm (cap ~10 mm entra) |

**Evitar:** Ø 8 / 10 / 12 / 13 mm · tubo sem fundo · industrial 16×2,5 mm.

| Link | Tipo |
|---|---|
| [Tubo ensaio vidro comum sem tampa — UN Global Trade](https://shopee.com.br/Tubo-de-Ensaio-Vidro-Comum-sem-Tampa-Borda-UN-Global-Trade-i.219768015.14233682454) | **Anúncio (escolhido)** — dropdown **16×100** ou **16×150** |
| [Shopee: tubo de ensaio 16x100](https://shopee.com.br/search?keyword=tubo%20de%20ensaio%2016x100) | Busca alternativa |
| [ML: tubo ensaio 16x100](https://lista.mercadolivre.com.br/tubo-de-ensaio-16x100) | Fallback Pacote B |

**Opcional depois (upgrade):** se achar borossilicato parede fina OD 15–16 mm, troca só o tubo; a cama 24×24 continua igual.

- [ ] B2 comprado **16×100 ou 16×150**, fundo fechado

---

## B3 — (Se A1 falhou) ZVS no ML Full

Tente achar **no mesmo vendedor** da fonte B1.

| Link | Tipo |
|---|---|
| [Busca Full: zvs 5-12v bobina](https://lista.mercadolivre.com.br/modulo-zvs-inducao-5-12v-bobina_Frete_Full_NoIndex_True) | **Busca** |
| [Smart Kits MA712 — R$ 49,90](https://www.smartkits.com.br/modulo-aquecedor-indutivo-5v-a-12v) | Loja (3º frete) |

- [ ] B3 comprado (só se necessário)

---

### Dica Pacote B

1. Abra o anúncio da **fonte** (B1).
2. Entre na **loja do vendedor** → procure ZVS + vidro.
3. Se tiver os três: **1 carrinho** = fonte + ZVS + vidro, frete **R$ 0**.

- [ ] **Pacote B comprado**

---

# Atalho — kit passivos (Pacote A)

Se a loja Shopee tiver kit Arduino básico, pode cobrir A5–A9 numa tacada:

| Link | Tipo |
|---|---|
| [Busca: kit componentes arduino basico](https://shopee.com.br/search?keyword=kit%20componentes%20arduino%20basico) | Busca Shopee |
| [Busca ML: kit componentes arduino](https://lista.mercadolivre.com.br/kit-componentes-eletronicos-arduino) | Busca ML |

Confira se o kit traz: pot 10k, botão momentâneo, rocker, fusível 10A, LEDs + 470 Ω.

---

# Cenários de total

### Principal — ZVS na Shopee

| Pacote | Total est. |
|---|---|
| A Shopee | R$ 130–140 |
| B ML Full | R$ 45 |
| **Soma** | **~R$ 175–185** |

### Alternativo — ZVS no ML (mesmo vendedor da fonte)

| Pacote | Total est. |
|---|---|
| A Shopee (sem ZVS) | R$ 85–95 |
| B ML (fonte + ZVS + vidro) | R$ 95 |
| **Soma** | **~R$ 180–190** |

---

# O que NÃO fazer

| Compra avulsa | Por quê |
|---|---|
| Saravati só MOSFET (R$ 7 + frete R$ 15) | Junta no Pacote A Shopee |
| Cinestec só TMP36 (R$ 14 + frete R$ 15) | Junta no Pacote A Shopee |
| Smart Kits só ZVS (R$ 50 + frete R$ 18) | Prefira Shopee ou ML Full |
| Fonte 5 A / 6 A | Mata o ZVS em carga |

---

# Ordem de compra

1. Montar **carrinho Shopee** (Pacote A) — não pagar até ter todos na mesma loja.
2. Montar **carrinho ML Full** (Pacote B).
3. Pagar os dois.
4. [BOM e fiação](BOM_E_FIACAO.md) → [firmware](firmware/indutor_dynavap.ino) → [afinação](AFINACAO_E_SEGURANCA.md).

---

# Mapa BOM → pacote

| # | Peça | Pacote |
|---|---|---|
| 1 | ZVS 5–12 V 120 W + bobina | **A** (ou **B3**) |
| 2 | MOSFET 15 A 400 W | **A** |
| 3 | Fonte 12 V 10 A | **B** |
| 4 | Arduino Nano V3 | **A** |
| 5–11 | Pot, botão, rocker, fusível, jack, LEDs | **A** |
| 12 | TMP36 | **A** |
| 13 | Tubo ensaio 16×100/150 fundo fechado | **B** (ou Shopee) |
| 14 | O-ring 15×3 | **A** |
| 15 | Cama cerâmica 24×24 mm | **A** |
| 16–17 | Fios | **A** |
| 18 | Caixa (STL próprio) | **A** / 3D |
| 19 | Ímã descanso 12×3 | **A16** |

**20/20** em **2 pacotes** (ou 3 só com fallback Smart Kits/Saravati).

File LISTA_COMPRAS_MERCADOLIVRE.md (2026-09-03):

# Lista de compras — Mercado Livre

CEP frete: **72120-250** (Taguatinga/DF; se o seu for outro, troque no checkout).  
Cotação automática do navegador foi bloqueada (login ML). Use os links abaixo logado, ordene por **Menor preço** e some o frete.

BOM completo: [BOM_E_FIACAO.md](BOM_E_FIACAO.md) · Shopee: [LISTA_COMPRAS_SHOPEE.md](LISTA_COMPRAS_SHOPEE.md)

## Como fechar cada item

1. Abrir o link de busca (conta logada)
2. Informar CEP `72120-250`
3. Ordenar por **Menor preço**
4. Abrir os 3 mais baratos; conferir spec + frete + reputação
5. Preferir **Full / frete grátis** se o delta for &lt; R$ 10
6. Marcar o vencedor na checklist

**Total estimado (só produto):** R$ 160–250 · **com frete DF:** some R$ 0–40 por vendedor.

---

## Checklist por peça

### 1. Módulo ZVS 5–12 V 120 W + bobina

- [ ] Comprado
- Busca: [módulo ZVS indução 5-12V bobina](https://lista.mercadolivre.com.br/modulo-zvs-inducao-5-12v-bobina)
- Busca alt.: [aquecedor indução ZVS 120W](https://lista.mercadolivre.com.br/aquecedor-inducao-zvs-120w)
- Faixa: R$ 35–80
- **Pegar:** 5–12 V, ~120 W, **com bobina**
- **Evitar:** 1000 W / 1800 W / 2500 W / 12–48 V

### 2. MOSFET trigger 15 A 400 W (XY-MOS / D4184)

- [ ] Comprado
- Busca: [módulo MOSFET 15A 400W PWM](https://lista.mercadolivre.com.br/modulo-mosfet-15a-400w-pwm)
- Busca alt.: [XY-MOS D4184](https://lista.mercadolivre.com.br/xy-mos-d4184)
- Anúncio relacionado (hotbed 25 A, também serve): [MLB-1565523372](https://produto.mercadolivre.com.br/MLB-1565523372-modulo-driver-mosfet-25a-para-mesa-aquecida-impressoras-3d-_JM)
- Faixa: R$ 8–25
- **Pegar:** 15 A / 400 W ou 25–30 A hotbed, bornes Vin/Vout/TRIG
- **Evitar:** IRF520 “mini” (corrente baixa demais para 10 A contínuos)

### 3. Fonte 12 V 10 A (ou 12 A)

- [ ] Comprado
- Busca: [fonte chaveada 12V 10A](https://lista.mercadolivre.com.br/fonte-chaveada-12v-10a)
- Anúncio exemplo: [MLB-4598773052](https://produto.mercadolivre.com.br/MLB-4598773052-fonte-chaveada-10a-12v-camera-cftv-dvr-fita-led-som-bivolt-_JM)
- Catálogo: [fonte 12V 10A 120W colmeia](https://www.mercadolivre.com.br/fonte-chaveada-12v-10a-120w-mgc-colmeia-cftv-cmera-seguranca-aluminio/p/MLB44562202)
- Faixa: R$ 40–80 (colmeia séria)
- **Pegar:** 12 V **≥ 10 A**, bivolt; jack 5,5×2,1 se for desk, ou bornes se for colmeia
- **Evitar:** 5 A / 6 A; “10 A” a R$ 15 sem marca/reputação (muitas mentem amperagem)

### 4. Arduino Nano (ATmega328)

- [ ] Comprado
- Busca: [Arduino Nano V3 ATmega328](https://lista.mercadolivre.com.br/arduino-nano-v3-atmega328)
- Faixa: R$ 20–45 (clone + cabo)
- **Pegar:** Nano V3 CH340/FT232, com cabo Mini-USB ou USB-C conforme o modelo
- **Evitar:** Nano Every / R4 (desnecessário e caro para este firmware)

### 5. Potenciómetro 10 kΩ linear

- [ ] Comprado
- Busca: [potenciómetro 10k linear](https://lista.mercadolivre.com.br/potenciometro-10k-linear)
- Faixa: R$ 3–8 (unitário) ou kit
- **Pegar:** B10K / linear; eixo 6 mm se for painel

### 6. Botão momentâneo SPST

- [ ] Comprado
- Busca: [botão momentâneo painel](https://lista.mercadolivre.com.br/botao-momentaneo-painel)
- Faixa: R$ 2–8
- **Pegar:** momentâneo (volta ao soltar), **não** latching
- **Evitar:** usar o botão para comutar os 10 A do ZVS

### 7. Interruptor geral rocker ≥ 6 A

- [ ] Comprado
- Busca: [chave rocker 12V 6A](https://lista.mercadolivre.com.br/chave-rocker-12v)
- Faixa: R$ 3–10
- **Pegar:** ≥ 6 A no positivo de 12 V

### 8. Fusível 10 A + suporte

- [ ] Comprado
- Busca: [fusível 10A lâmina suporte](https://lista.mercadolivre.com.br/fusivel-10a-lamina-suporte)
- Busca alt.: [porta fusível 10A DC](https://lista.mercadolivre.com.br/porta-fusivel-10a)
- Faixa: R$ 5–15
- **Pegar:** 10 A no positivo, o mais perto da fonte

### 9. Jack DC fêmea 5,5 × 2,1 mm

- [ ] Comprado
- Busca: [jack DC 5.5 2.1 fêmea](https://lista.mercadolivre.com.br/jack-dc-5.5-2.1-femea)
- Faixa: R$ 3–8
- Só necessário se a fonte for com plug P4; colmeia com bornes dispensa

### 10–11. LED 5 mm + resistor 470 Ω

- [ ] Comprado
- Busca: [LED 5mm + resistor 470 ohm](https://lista.mercadolivre.com.br/led-5mm-resistor-470)
- Faixa: R$ 1–5 (kit)
- 2 LEDs (câmara + status) + 2× 470 Ω (ou 220–470 Ω)

### 12. Sensor TMP36

- [ ] Comprado
- Busca: [sensor temperatura TMP36](https://lista.mercadolivre.com.br/sensor-temperatura-tmp36)
- Faixa: R$ 8–20
- **Pegar:** TMP36 TO-92
- **Alternativa:** NTC 10 kΩ + resistor 10 kΩ (exige ajuste do firmware)

### 13. Tubo de vidro ~16 mm (parede fina)

- [ ] Comprado
- Busca: [tubo vidro borossilicato 16mm](https://lista.mercadolivre.com.br/tubo-vidro-borossilicato-16mm)
- Busca alt.: [tanque Cloupor Cloutank M3 vidro](https://lista.mercadolivre.com.br/cloupor-cloutank-m3-vidro)
- Faixa: R$ 10–30
- **Pegar:** Ø externo ~16 mm, **parede fina (~1 mm)**, comprimento ~40–60 mm
- **Evitar:** tubo industrial 16×2,5 mm (ID ~11 mm — cap pode não entrar)

### 14. O-ring 15 × 3 mm

- [ ] Comprado
- Busca: [o-ring 15x3](https://lista.mercadolivre.com.br/o-ring-15x3)
- Faixa: R$ 2–8 (pacote)

### 15. Trava de altura

- [ ] Comprado / improvisado
- Busca: [cavilha madeira 16mm](https://lista.mercadolivre.com.br/cavilha-madeira-16mm) ou cortiça / silicone
- Faixa: R$ 0–15
- Precisa ser **ajustável** (parafuso / empurrar)

### 16–17. Fio potência + sinal

- [ ] Comprado
- Busca potência: [fio 16 AWG silicone](https://lista.mercadolivre.com.br/fio-16-awg-silicone) ou 18 AWG
- Busca sinal: [fio jumper 22 AWG](https://lista.mercadolivre.com.br/fio-22-awg) / kit jumper
- Faixa: R$ 5–20

### 18. Caixa / gabinete

- [ ] Impresso (pack v1)
- **STL oficial:** [lisa](caixa-3d/print/v1-lisa/), [relevo](caixa-3d/print/v1/) ou [cavas](caixa-3d/print/v1-cavas/) — [guia](caixa-3d/README.md)
- Faixa: R$ 0–40 (PETG)
- **Pegar:** frestas de ar nos dissipadores do ZVS (já no STL)

### 19. (Opcional) Fio esmaltado 16 AWG

- [ ] Comprado
- Busca: [fio esmaltado 16 AWG](https://lista.mercadolivre.com.br/fio-esmaltado-16-awg)
- Faixa: R$ 10–20
- Só se for rebobinar a bobina no tubo

---

## Kit “passivos” (agrupar no mesmo vendedor)

Se o frete do CEP pesar, compre num único anúncio/kit:

`potenciómetro 10k + botão momentâneo + chave rocker + fusível 10A + jack 5.5x2.1 + LED 5mm + resistor 470 + fio`

Busca: [kit componentes eletrônicos arduino](https://lista.mercadolivre.com.br/kit-componentes-eletronicos-arduino)

---

## Fallbacks com preço confirmado (fora do ML)

Use se o ML estiver caro, sem estoque ou com frete absurdo para 72120-250.

| Peça | Preço | Link |
|---|---|---|
| ZVS 5–12 V 120 W + bobina | **R$ 49,90** | [Smart Kits MA712](https://www.smartkits.com.br/modulo-aquecedor-indutivo-5v-a-12v) |
| ZVS (alt.) | R$ 77,90 Pix | [SmartProjects WP6-J6](https://www.smartprojectsbrasil.com.br/mini-modulo-de-aquecimento-por-inducao-zvs-com-bobina) |
| MOSFET 15 A 400 W | R$ 12,90 | [Saravati](https://www.saravati.com.br/modulo-controlador-pwm-n-mos-mosfet-5v-a-36v-15a-400w.html) |
| MOSFET (alt.) | R$ 24,60 Pix | [MakerHero D4184](https://www.makerhero.com/produto/modulo-mosfet-d4184a-15a/) |
| Arduino Nano V3 + cabo | R$ 24,60 Pix | [MakerHero](https://www.makerhero.com/produto/placa-nano-v3-0-cabo-usb-para-arduino/) |
| TMP36 | R$ 13,50 | [Cinestec](https://www.cinestec.com.br/tmp36-to-92-sensor-temperatura) |
| TMP36 (alt.) | R$ 17,96 Pix | [RS Robótica](https://www.rsrobotica.com.br/produto/sensor-de-temperatura-tmp36-to92.html) |
| Tubo Ø16 mm | R$ 13,00 | [VaptBR](https://www.vaptbr.com.br/produtos/tubo-diam-160mm-x-25mm-borossilicato-tubo-de-vidro-borossilicato-3-3-diametro-160mm/) — conferir **parede fina**; 16×2,5 mm pode travar o cap |

**Carrinho híbrido sugerido:** ZVS Smart Kits + MOSFET Saravati + Nano Shopee + TMP36 Cinestec + fonte/passivos no ML Full. Total produto ~**R$ 175–250** + fretes. Ver [lista híbrida](LISTA_COMPRAS_HIBRIDA.md).

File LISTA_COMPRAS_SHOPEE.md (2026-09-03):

# Lista de compras — Shopee

CEP frete: **72120-250** (Taguatinga/DF; se o seu for outro, troque no checkout).  
Cotação automática do navegador foi bloqueada (verificação de tráfego). Use os links abaixo no app/site logado, ordene por **Preço** (menor) e some o frete.

BOM completo: [BOM_E_FIACAO.md](BOM_E_FIACAO.md) · Mercado Livre: [LISTA_COMPRAS_MERCADOLIVRE.md](LISTA_COMPRAS_MERCADOLIVRE.md)

## Como fechar cada item

1. Abrir o link de busca (conta logada)
2. Informar CEP `72120-250`
3. Ordenar por **Preço** (menor primeiro); filtrar **Envio nacional** / **Shopee Garantida** quando possível
4. Abrir os 3 mais baratos; conferir spec + frete + avaliações
5. Preferir frete grátis / Xpress se o delta for &lt; R$ 10
6. Marcar o vencedor na checklist

**Total estimado (só produto):** R$ 150–240 · **com frete DF:** some R$ 0–35 por loja.  
Histórico de agregadores: ZVS ~R$ 40–68 · MOSFET XY-MOS ~R$ 9–16.

---

## Checklist por peça

### 1. Módulo ZVS 5–12 V 120 W + bobina

- [ ] Comprado
- Busca: [ZVS indução 5V 12V 120W bobina](https://shopee.com.br/search?keyword=zvs%20inducao%205v%2012v%20120w%20bobina)
- Busca alt.: [módulo ZVS aquecimento indução](https://shopee.com.br/search?keyword=modulo%20zvs%20aquecimento%20inducao)
- Faixa: R$ 35–70
- **Pegar:** DC 5–12 V, max ~120 W, **com bobina**
- **Evitar:** 1000 W / 1800 W / 2500 W / 12–48 V (fundição de metal)

### 2. MOSFET trigger 15 A 400 W (XY-MOS / D4184)

- [ ] Comprado
- Busca: [MOSFET PWM 15A 400W](https://shopee.com.br/search?keyword=mosfet%20pwm%2015a%20400w)
- Busca alt.: [XY-MOS D4184](https://shopee.com.br/search?keyword=xy-mos%20d4184)
- Faixa: R$ 9–18
- **Pegar:** dual MOSFET 15 A / 400 W, bornes de parafuso, TRIG 3,3–20 V
- **Evitar:** IRF520 sozinho para 10 A contínuos

### 3. Fonte 12 V 10 A (ou 12 A)

- [ ] Comprado
- Busca: [fonte chaveada 12V 10A](https://shopee.com.br/search?keyword=fonte%20chaveada%2012v%2010a)
- Busca alt.: [fonte colmeia 12V 10A 120W](https://shopee.com.br/search?keyword=fonte%20colmeia%2012v%2010a%20120w)
- Faixa: R$ 35–75
- **Pegar:** 12 V **≥ 10 A**, bivolt
- **Evitar:** 5 A / 6 A; fontes “10 A” absurdamente baratas sem review

### 4. Arduino Nano (ATmega328)

- [ ] Comprado
- Busca: [Arduino Nano V3 ATmega328 cabo](https://shopee.com.br/search?keyword=arduino%20nano%20v3%20atmega328%20cabo)
- Faixa: R$ 18–40
- **Pegar:** clone Nano V3 + cabo USB
- **Evitar:** Nano R4 / Every (caro demais para este projeto)

### 5. Potenciómetro 10 kΩ linear

- [ ] Comprado
- Busca: [potenciómetro 10k linear](https://shopee.com.br/search?keyword=potenciometro%2010k%20linear)
- Faixa: R$ 2–8 (ou kit 5–10 peças)

### 6. Botão momentâneo SPST

- [ ] Comprado
- Busca: [botão momentâneo metal 16mm](https://shopee.com.br/search?keyword=botao%20momentaneo%20painel) ou [push button momentâneo](https://shopee.com.br/search?keyword=push%20button%20momentaneo)
- Faixa: R$ 2–10
- **Pegar:** momentâneo (não trava ligado)

### 7. Interruptor geral rocker ≥ 6 A

- [ ] Comprado
- Busca: [chave rocker KCD1 12V](https://shopee.com.br/search?keyword=chave%20rocker%20kcd1)
- Faixa: R$ 2–8

### 8. Fusível 10 A + suporte

- [ ] Comprado
- Busca: [fusível 10A + suporte](https://shopee.com.br/search?keyword=fusivel%2010a%20suporte)
- Busca alt.: [inline fuse holder 10A](https://shopee.com.br/search?keyword=porta%20fusivel%20inline%2010a)
- Faixa: R$ 4–15

### 9. Jack DC fêmea 5,5 × 2,1 mm

- [ ] Comprado
- Busca: [jack DC 5.5x2.1 fêmea](https://shopee.com.br/search?keyword=jack%20dc%205.5%202.1%20femea)
- Faixa: R$ 2–8
- Dispensável se a fonte for colmeia com bornes

### 10–11. LED 5 mm + resistor 470 Ω

- [ ] Comprado
- Busca: [LED 5mm kit resistor](https://shopee.com.br/search?keyword=led%205mm%20kit%20resistor)
- Faixa: R$ 1–8
- Precisa de 2 LEDs + resistores 220–470 Ω

### 12. Sensor TMP36

- [ ] Comprado
- Busca: [TMP36 sensor temperatura](https://shopee.com.br/search?keyword=tmp36%20sensor%20temperatura)
- Faixa: R$ 8–20
- **Alternativa barata:** [NTC 10k](https://shopee.com.br/search?keyword=ntc%2010k) + resistor 10 kΩ (firmware precisa adaptação)

### 13. Tubo de vidro ~16 mm (parede fina)

- [ ] Comprado
- Busca: [tubo vidro 16mm borossilicato](https://shopee.com.br/search?keyword=tubo%20vidro%2016mm%20borossilicato)
- Busca alt.: [Cloutank M3 glass](https://shopee.com.br/search?keyword=cloutank%20m3%20glass) / tanque vidro 16 mm
- Faixa: R$ 10–30
- **Pegar:** Ø ~16 mm externo, parede fina, 40–60 mm de comprimento
- **Evitar:** tubo grosso (parede 2–2,5 mm) que reduz o diâmetro interno e trava o cap

### 14. O-ring 15 × 3 mm

- [ ] Comprado
- Busca: [o-ring 15x3 mm](https://shopee.com.br/search?keyword=o-ring%2015x3)
- Faixa: R$ 2–10 (pacote)

### 15. Trava de altura

- [ ] Comprado / improvisado
- Busca: [cavilha 16mm](https://shopee.com.br/search?keyword=cavilha%2016mm) / [rolha cortiça](https://shopee.com.br/search?keyword=rolha%20cortica%20pequena)
- Faixa: R$ 0–15

### 16–17. Fio potência + sinal

- [ ] Comprado
- Busca: [fio silicone 16 AWG](https://shopee.com.br/search?keyword=fio%20silicone%2016%20awg)
- Busca sinal: [fio jumper macho fêmea](https://shopee.com.br/search?keyword=fio%20jumper%20arduino)
- Faixa: R$ 5–20

### 18. Caixa / gabinete

- [ ] Impresso (pack v1)
- **STL oficial:** [lisa](caixa-3d/print/v1-lisa/), [relevo](caixa-3d/print/v1/) ou [cavas](caixa-3d/print/v1-cavas/) — [guia](caixa-3d/README.md)
- Faixa: R$ 0–40 (PETG)
- Ventilação traseira já no modelo

### 19. (Opcional) Fio esmaltado 16 AWG

- [ ] Comprado
- Busca: [fio esmaltado 1.3mm](https://shopee.com.br/search?keyword=fio%20esmaltado%201.3mm) (~16 AWG) ou `fio esmaltado 16 awg`
- Faixa: R$ 8–20

---

## Kit “passivos” (mesmo seller)

Agrupar para economizar frete:

`pot 10k + botão + rocker + fusível 10A + jack DC + LEDs + resistores + jumper`

Busca: [kit componentes Arduino básico](https://shopee.com.br/search?keyword=kit%20componentes%20arduino%20basico)

---

## Fallbacks com preço confirmado (fora da Shopee)

| Peça | Preço | Link |
|---|---|---|
| ZVS 5–12 V 120 W + bobina | **R$ 49,90** | [Smart Kits MA712](https://www.smartkits.com.br/modulo-aquecedor-indutivo-5v-a-12v) |
| ZVS (alt.) | R$ 77,90 Pix | [SmartProjects WP6-J6](https://www.smartprojectsbrasil.com.br/mini-modulo-de-aquecimento-por-inducao-zvs-com-bobina) |
| MOSFET 15 A 400 W | R$ 12,90 | [Saravati](https://www.saravati.com.br/modulo-controlador-pwm-n-mos-mosfet-5v-a-36v-15a-400w.html) |
| Arduino Nano V3 + cabo | R$ 24,60 Pix | [MakerHero](https://www.makerhero.com/produto/placa-nano-v3-0-cabo-usb-para-arduino/) |
| TMP36 | R$ 13,50 | [Cinestec](https://www.cinestec.com.br/tmp36-to-92-sensor-temperatura) |
| Tubo Ø16 mm | R$ 13,00 | [VaptBR](https://www.vaptbr.com.br/produtos/tubo-diam-160mm-x-25mm-borossilicato-tubo-de-vidro-borossilicato-3-3-diametro-160mm/) — conferir parede; preferir tanque fino tipo Cloupor M3 |

**Estratégia barata típica na Shopee:** MOSFET + Nano + passivos em 1–2 lojas Full; ZVS nacional em [Smart Kits](https://www.smartkits.com.br/modulo-aquecedor-indutivo-5v-a-12v); fonte 10 A no ML Full. Ver [lista híbrida](LISTA_COMPRAS_HIBRIDA.md).

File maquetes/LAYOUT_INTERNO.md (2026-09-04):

# Layout interno — mesa v1 (maquete 1.1)

**Caixa física congelada:** 92 × 58 × 65 mm + tampa 8 mm. Furos = [`../caixa-3d/box_params.scad`](../caixa-3d/box_params.scad). Esta doc só organiza o **interior**.

Fonte de verdade: [`dimensions.json`](dimensions.json) (precisão **0,1 mm**). Viewer: [`viewer.html`](viewer.html) (fetch do JSON).

Aprendizado do portátil ([`indutor-dynavap-portatil/LAYOUT_COMPACTO.md`](../../indutor-dynavap-portatil/LAYOUT_COMPACTO.md)): `catalog_mm`, clearances, ZVS achatado, cama Ø24×8, bobina ID16, stack Y — **sem** trazer o pack 18650 para esta caixa.

---

## Coordenadas

| Eixo | Sentido |
|---|---|
| Origem | Centro da base externa |
| X | − esquerda · + câmara (tubo em **28**) |
| Y | Altura · + cima |
| Z | + frente (painel) · − traseira (vents) |

Interno: X ∈ [−43,5 … 43,5], Y ∈ [2,5 … 62,5], Z ∈ [−26,5 … 26,5].

---

## Baias

```mermaid
flowchart LR
  subgraph elec [BaiaEletronica]
    zvs["ZVS_piso"]
    mos["MOSFET_acima"]
    nano["Nano_topo"]
  end
  subgraph cam [BaiaCamara_X28]
    bed["Cama_24x8"]
    tube["Tubo_16x42"]
    coil["Bobina_ID16"]
  end
  vents["Vents_-Z"] --> zvs
  elec -->|"X_lt_16"| cam
```

| Zona | X | Conteúdo |
|---|---|---|
| Eletrônica | &lt; 16 | ZVS, MOSFET, Nano, TMP36 |
| Câmara | eixo 28 | Cama, tubo, bobina, O-ring, Dynavap |

O bolsão lateral de ~19 mm do portátil **não cabe** (Z interno = 53 mm). Por isso MOSFET e Nano sobem no eixo Y.

---

## Stack Y — eletrônica

| Face | Y (mm) |
|---|---|
| Piso interno | 2,5 |
| Centro ZVS (H=20) | 12,5 |
| Topo ZVS | 22,5 |
| Base MOSFET (standoff 2) | 24,5 |
| Centro MOSFET | 30,5 |
| Centro Nano (H=11) | 46,0 |
| Topo Nano | 51,5 |
| Face interna tampa | 62,5 |

## Stack Y — câmara (X=28)

| Face | Y (mm) |
|---|---|
| Cama Ø24×8 | 2,5 → 10,5 |
| Tubo Ø16×42 | 10,5 → 52,5 |
| Bobina (4 espiras) | 36 / 42 / 48 / 54 |
| O-ring no collarinho | ~66 |
| Ímã (tampa) | 70 → 73 |

---

## Catálogo (mm)

| Peça | Envelope |
|---|---|
| ZVS | 55 × 37 × 20 |
| XY-MOS | 34 × 17 × 12 |
| Nano | 43,2 × 17,8 × 11 |
| Cama | Ø24 × 8 |
| Tubo | Ø16 × 42 (ID14) |
| Bobina | ID16 / OD22 |
| M7 | Ø10 × 92 + cap Ø10 × 27 |

---

## Clearances mínimos

| Par | Min (mm) |
|---|---|
| ZVS ↔ parede | 3 |
| ZVS ↔ tubo (X) | 2 |
| MOSFET ↔ ZVS (Y) | 2 |
| Nano ↔ tampa | 3 |
| Bobina OD ↔ parede | 2 |

Lista completa em `dimensions.json` → `clearance_checks`.

---

## Fluxo térmico

Inlet traseiro (4 × 10 × 4) → fins do ZVS → sobe sob a tampa. **Não** vedar a tampa. TMP36 na face −Z do dissipador.

Trilha 12 V curta: jack → fusível painel → rocker → MOSFET → ZVS.

---

## O que não fazer

- Mover furos / regenerar STL da caixa enquanto a v1 impressa não for medida
- Duplicar fusível interno (só o porta-fusível de painel)
- Modelar cama como torre 24 mm ou bobina com ID &lt; 16
- Empurrar pack 18650 nesta caixa (repo portátil)
- Encerrar hermético / encostar dissipador no PETG

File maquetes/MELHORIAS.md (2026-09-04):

# Melhorias — v1 fechada e backlog v2

A **v1 desktop** está fechada (set/2026): caixa [lisa](../caixa-3d/print/v1-lisa/), [relevo AMS](../caixa-3d/print/v1/) ou [cavas](../caixa-3d/print/v1-cavas/), furos alinhados ao BOM, firmware lento, fonte 12 V 10 A na tomada.

O [visualizador](viewer.html) e [dimensions.json](dimensions.json) **v1.1** descrevem o interior com precisão 0,1 mm ([LAYOUT_INTERNO.md](LAYOUT_INTERNO.md)). A caixa física (furos/STL) permanece congelada. Não edite FreeCAD/acsdog para a v1.

---

## Já na v1 (não refazer)

- Painel: gangorra redonda Ø20,2 · pot Ø7,6 · botão Ø19,2 · LEDs Ø5,2
- Traseira: jack Ø8,2 · porta-fusível 5×20 Ø13,2 · vents 4×10×4
- Tampa: bocal à direita, ímã X=−14 no centro do tribal
- Tribal opcional: lisa · relevo AMS · cavas + cola
- TMP36 no dissipador, fios 16 AWG curtos, tubo ensaio + cama **Ø24×8** — ver [MONTAGEM.md](MONTAGEM.md) · [LAYOUT_INTERNO.md](LAYOUT_INTERNO.md)
- Maquete **v1.1**: ZVS no piso, MOSFET empilhado, Nano acima; sem colisões AABB documentadas

---

## Ainda vale na montagem (não é CAD)

| Item | Ação |
|---|---|
| Ventilação | Não colar a tampa hermética; não tape os vents |
| TMP36 | Pasta térmica no dissipador do ZVS; Serial `Ts=` plausível |
| Fios 12 V | Loop curto jack → fusível → gangorra → MOSFET → ZVS |
| LED D6 | Apontar para o tubo, não para o olho |
| Placas | Parafusar ZVS/MOSFET; Nano isolado da parede |

---

## Legado (não usar na v1)

ZIP [acsdog Printables](https://www.printables.com/model/1067938-dynavap-induction-heater-box-with-pwm) e edição FreeCAD — só referência histórica. A caixa oficial é OpenSCAD neste repo.

Coil chuck do acsdog continua **opcional** se for rebobinar 16 AWG na mesa.

---

## Backlog v2 (não entra nesta versão)

- Pack 18650/21700 + BMS adequado (≥10 A) — **não** power bank de celular
- Gangorra com LED que acenda em **12 V DC** (o kit 127/220 V AC não ilumina)
- Viewer carregando o STL real (`STLLoader`)
- Ajustes pós-impressão medidos na peça física → atualizar `dimensions.json` (furos só se a caixa for refeita)

Depois de montar, compare a caixa real com o viewer e anote desvios aqui.

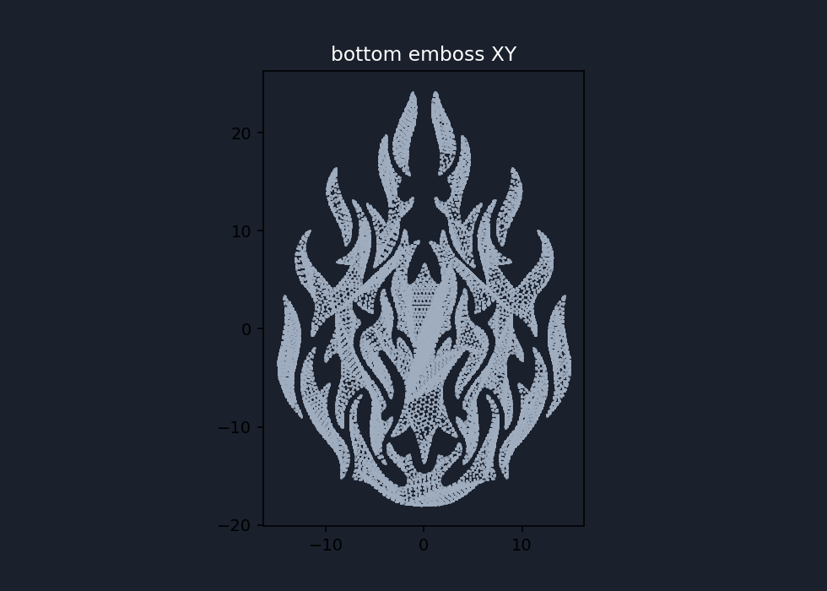
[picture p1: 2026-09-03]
caixa-3d/stl/previews/diag_bottom_xy.png

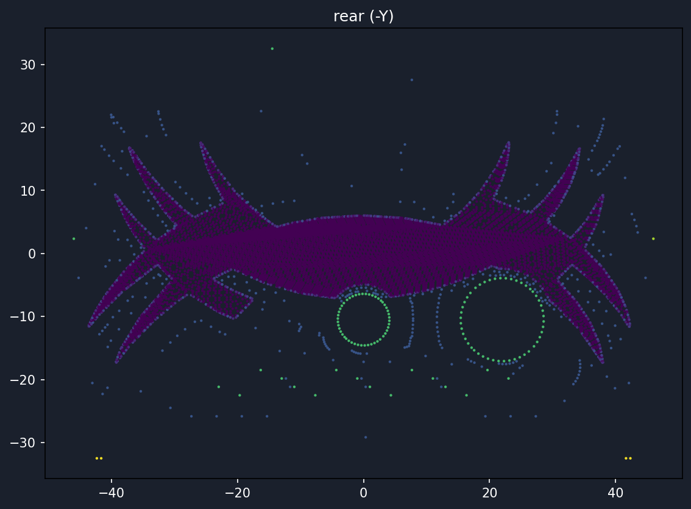
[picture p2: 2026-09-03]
caixa-3d/stl/previews/ortho_rear.png

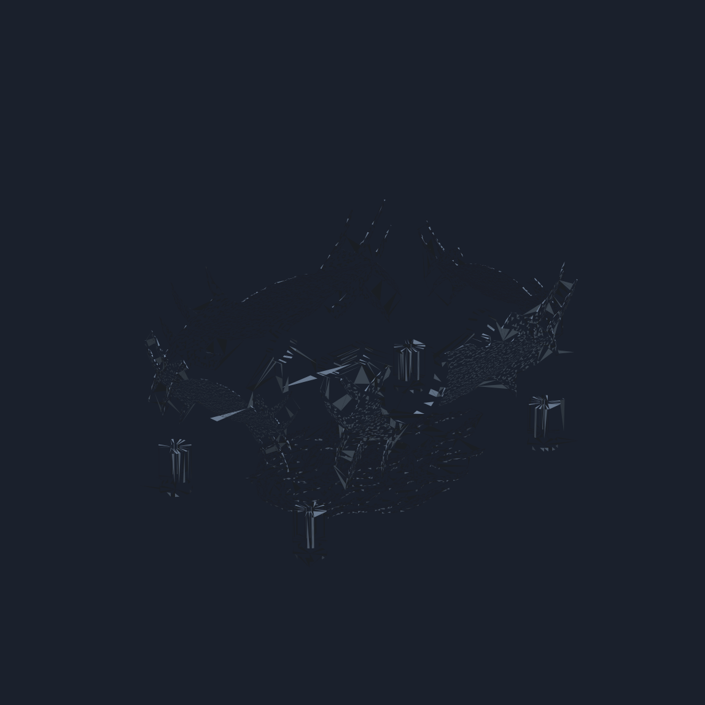
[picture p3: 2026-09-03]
caixa-3d/stl/previews/body_iso.png

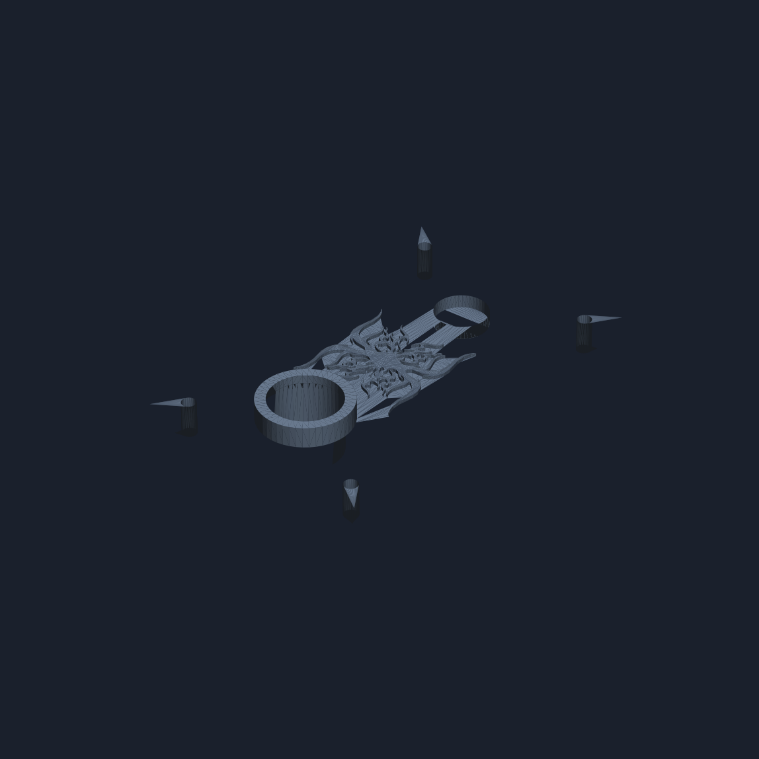
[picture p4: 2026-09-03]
caixa-3d/stl/previews/lid_iso.png

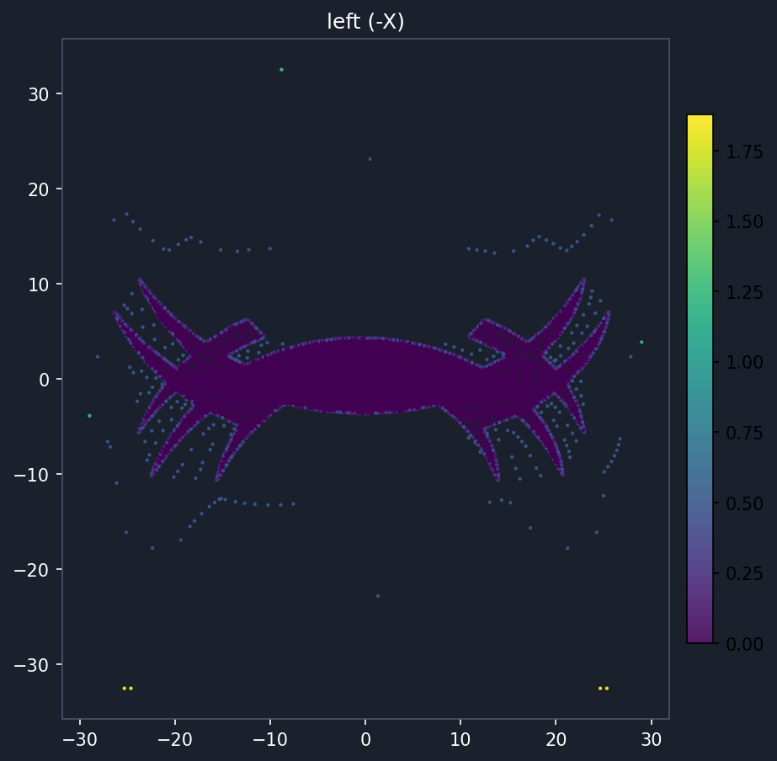
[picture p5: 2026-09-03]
caixa-3d/stl/previews/ortho_left.png

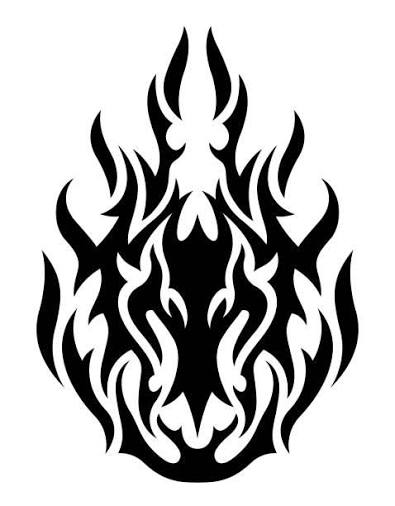
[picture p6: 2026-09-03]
caixa-3d/decals/src/tribal_3.jpg

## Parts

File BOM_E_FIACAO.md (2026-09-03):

# BOM Brasil e fiação

Lista para a v1 de mesa. Estimativa **R$ 150–280** conforme AliExpress vs loja nacional. Não compre o ZVS 12–48 V / 1800 W.

Depois de soldar: [firmware](firmware/indutor_dynavap.ino) e [afinação](AFINACAO_E_SEGURANCA.md).

---

## Lista de peças

| # | Peça | Spec | Onde | Faixa |
|---|---|---|---|---|
| 1 | Módulo ZVS com bobina | **5–12 V, 120 W** | [Smart Kits MA712](https://www.smartkits.com.br/modulo-aquecedor-indutivo-5v-a-12v) R$ 49,90, [SmartProjects](https://www.smartprojectsbrasil.com.br/mini-modulo-de-aquecimento-por-inducao-zvs-com-bobina), ML/Shopee | R$ 25–80 |
| 2 | MOSFET trigger | 15 A ou **30 A / 400 W**, bornes Vin / Vout / TRIG | AliExpress, ML, kits VapOven | R$ 8–25 |
| 3 | Fonte | **12 V 10 A** (folga 12 A), jack 5,5 × 2,1 mm | ML, fontes de LED/CFTV | R$ 40–80 |
| 4 | Arduino Nano | ATmega328, Mini-USB ou USB-C | ML, lojas de Arduino | R$ 25–50 |
| 5 | Potenciómetro | 10 kΩ linear, eixo 6 mm | qualquer eletrônica | R$ 3–8 |
| 6 | Botão | Momentâneo **SPST** (não use o botão para os 10 A) | — | R$ 2–8 |
| 7 | Interruptor geral | Gangorra **redonda Ø20 mm**, ≥ 6 A no positivo 12 V | Shopee A7 | R$ 3–10 |
| 8 | Fusível | **10 A** vidro 5×20 + **porta painel** (traseira) | Shopee A8 | R$ 5–15 |
| 9 | Jack DC fêmea | **DC-022** 5,5 × 2,1 mm, painel | Shopee A15 | R$ 3–8 |
| 10 | LED câmara | 5 mm + resistor **470 Ω** ¼ W | — | R$ 1 |
| 11 | LED status | 5 mm (pode ser o onboard do Nano) | — | — |
| 12 | Sensor | **TMP36** no dissipador do ZVS (alternativa: NTC 10 kΩ + 10 kΩ) | ML | R$ 5–15 |
| 13 | Tubo de vidro | Ensaio **16×100/150**, vidro comum, **fundo fechado**; cortar ~40–50 mm | Shopee B2 | R$ 3–15 |
| 14 | O-ring | 15 × 3 mm | — | R$ 2 |
| 15 | Cama cerâmica | Roldana isolador **24×24 mm** (chocadeira) **sob** o fundo do tubo — não entra no tubo | Shopee A13 | R$ 10–20 |
| 16 | Fio potência | 16–18 AWG, trechos curtos | — | R$ 5 |
| 17 | Fio sinal | 22 AWG (botão, LED, sensor) | — | — |
| 18 | Caixa | Pack v1 [lisa](caixa-3d/print/v1-lisa/), [relevo](caixa-3d/print/v1/) ou [cavas](caixa-3d/print/v1-cavas/); 92×58×65 + tampa 8 | A14 | R$ 0–40 |
| 19 | Ímã descanso | Disco neodímio **Ø12×3 mm** (preferir diametral) colado no topo esquerdo da tampa | A16 | R$ 3–25 |
| 20 | Opcional | Fio esmaltado **16 AWG** para rebobinar | — | R$ 10–20 |

Kit VapOven mains (~£45) já traz ZVS, MOSFET, botão, jack, vidro, fonte e cavilha — falta Arduino, pot, fusível, TMP36 e caixa. Frete UK costuma anular a vantagem.

---

## O que não comprar

- ZVS 12–48 V / 1000–2500 W (fundição de metal)
- Fonte 12 V **6 A** (cai a tensão e mata o ZVS)
- LiPo de drone
- Botão de painel como único interruptor do ZVS
- Módulo PWM de kHz direto no TRIG sem o firmware lento deste repo

---

## Pinos do Arduino Nano

| Função | Pino | Nota |
|---|---|---|
| Botão momentâneo | **D2** | O outro lado em GND; pull-up interno |
| TRIG do MOSFET | **D3** | HIGH = ZVS ligado. Se o módulo for “active LOW”, inverter `MOSFET_ACTIVE_HIGH` no sketch |
| LED status | **D5** | + resistor 220–470 Ω se for LED externo |
| LED câmara | **D6** | Série com 470 Ω para GND |
| Potenciómetro | **A0** | Cursores: 5 V — A0 — GND |
| TMP36 | **A1** | +Vs → 5 V, Vout → A1, GND → GND. Corpo do sensor no **dissipador** do ZVS, não no cap |

Nano alimentado pelo 5 V regulado: ligue **VIN** no 12 V **depois** do interruptor geral (o regulador do Nano aguenta 12 V) **ou** use um buck 12 V → 5 V em `5V` se o Nano esquentar. GND comum com fonte, MOSFET e ZVS.

---

## Diagrama de blocos

```mermaid
flowchart TD
  wall["Tomada"] --> psu["Fonte 12V 10A"]
  psu --> jack["Jack 5.5 x 2.1"]
  jack --> sw["Interruptor geral"]
  sw --> fuse["Fusivel 10A"]
  fuse --> vinP["12V_SW"]
  gnd["GND fonte"] --> nanoG["GND Nano"]
  gnd --> mosG["V- MOSFET"]
  vinP --> nanoVin["VIN Nano"]
  vinP --> mosIn["V+ in MOSFET"]
  nano["Nano D3"] --> trig["TRIG MOSFET"]
  btn["Botao D2"] --> nano
  pot["Pot A0"] --> nano
  tmp["TMP36 A1"] --> nano
  mosOut["V+ out MOSFET"] --> zvsP["ZVS +"]
  gnd --> zvsG["ZVS -"]
  zvsP --> coil["Bobina 16 mm"]
  zvsG --> coil
```

---

## Fiação ASCII (potência vs sinal)

```
FONTE 12V 10A
  + ---- jack ---- interruptor ---- fusivel 10A ----+---- VIN Nano
                                                    |
                                                    +---- V+ in  MOSFET
  - ------------------------------------------------+---- GND Nano
                                                    +---- V- in  MOSFET
                                                    +---- ZVS -
                                                    +---- botão (lado GND)
                                                    +---- TMP36 GND
                                                    +---- pot GND
                                                    +---- LEDs (cátodo via resistor)

MOSFET
  V+ out  ------------------------------------------- ZVS +
  TRIG    ------------------------------------------- Nano D3
  (V- out, se existir, junto com V- in / GND)

ZVS
  bornes da bobina ---- soldar a bobina (não confiar no borne de plástico)
  bobina ---- ao redor do TUBO 16 mm ---- fundo de vidro = stop do cap
  ímã Ø12×3 ---- cavidade na TAMPA (descanso upright, não é trava)

Nano
  D2 ---- botão ---- GND
  D5 ---- LED status ---- 470Ω ---- GND
  D6 ---- LED câmara (olhando o tubo) ---- 470Ω ---- GND
  A0 ---- cursor do pot; extremos 5V e GND
  A1 ---- Vout TMP36; +Vs = 5V
```

O MOSFET comuta o **positivo** entre fonte e ZVS. O botão só mexe em D2. Corrente da bobina **nunca** passa pelo Arduino nem pelo SPST.

Módulos MOSFET 15 A típicos:

| Borne | Liga em |
|---|---|
| Vin+ / V+ in | 12 V depois do fusível |
| Vin− / V− in | GND |
| Vout+ / V+ out | ZVS + |
| Vout− / V− out | ZVS − (ou deixe o ZVS − direto no GND da fonte) |
| TRIG / PWM | Nano D3 (e GND de sinal se o módulo tiver pino SIG−) |

Referência visual VapOven: [MOSFET wiring](https://vapoven.com/mosfet-wiring-diagram/) — o fio do gatilho vai a qualquer pad TRIG/PWM. Aqui o gatilho é o D3, não o botão cru.

---

## Ordem de montagem elétrica

1. Fonte → jack → interruptor → fusível. Multímetro: 12 V estável **sem** ZVS.
2. Ligar só o Nano (VIN/GND), gravar o firmware, confirmar LED e Serial.
3. MOSFET **sem** ZVS: D3 HIGH deve aparecer 12 V em V+ out.
4. Bobina no ar, ZVS nos bornes. Primeiro pulso **curto**. Se a fonte piscar ou a tensão cair abaixo de ~11,5 V, desligar — bobina curta ou fonte fraca.
5. Só então tubo, cama cerâmica, caixa e ímã na tampa. Afinação: [AFINACAO_E_SEGURANCA.md](AFINACAO_E_SEGURANCA.md).

Fios de potência curtos e grossos. Fios longos viram indutância extra e atrapalham o ZVS.

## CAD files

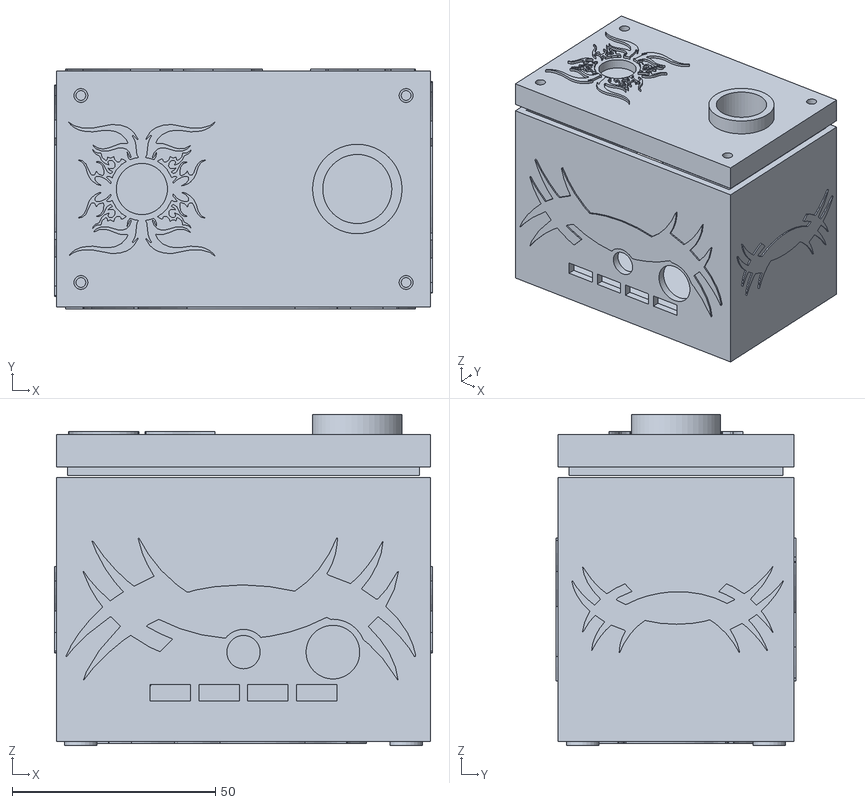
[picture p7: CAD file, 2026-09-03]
caixa-3d/stl/box_assembly_preview.stl
93.0 x 59.0 x 81.5

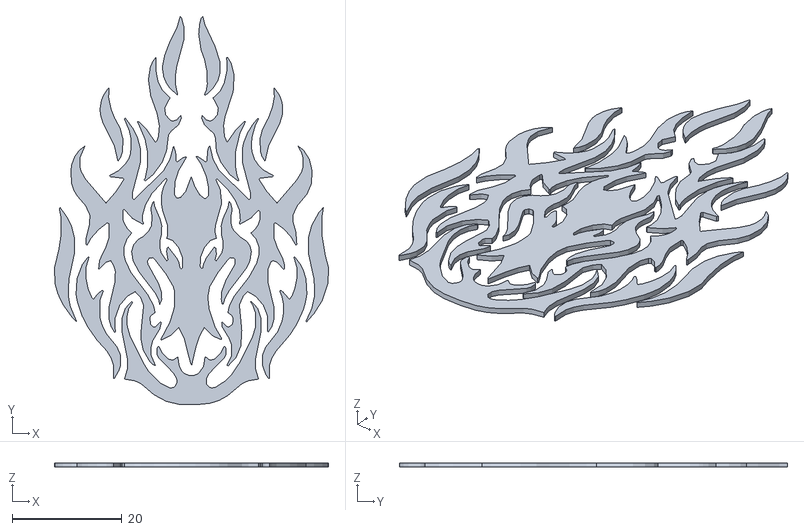
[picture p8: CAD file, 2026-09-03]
caixa-3d/decals/tribal_3_emboss.stl
50.0 x 70.9 x 0.8

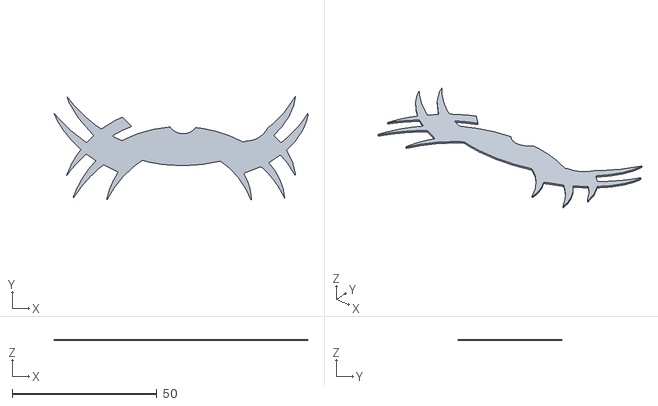
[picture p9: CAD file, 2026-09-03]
caixa-3d/print/v1-cavas/decal_tras.stl
87.7 x 35.9 x 0.5

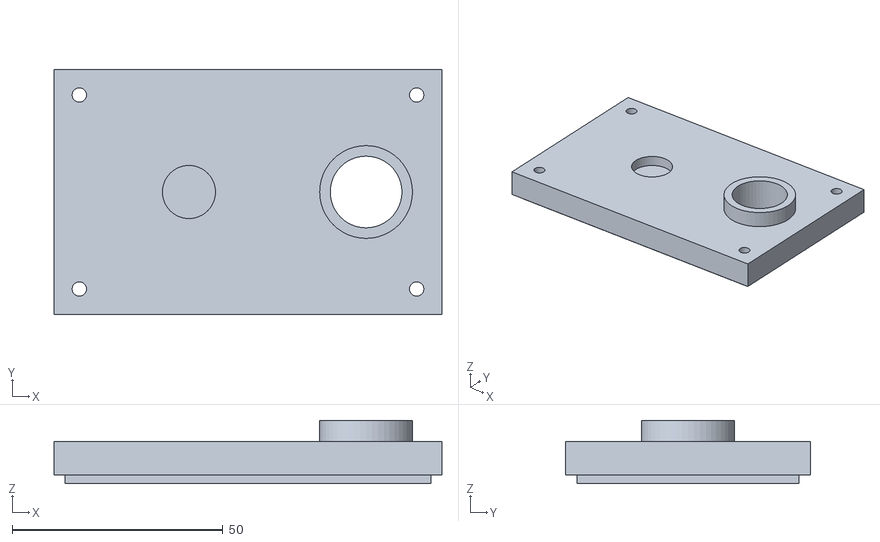
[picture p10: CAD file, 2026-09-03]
caixa-3d/print/v1-lisa/tampa_lisa.stl
92.0 x 58.0 x 15.0

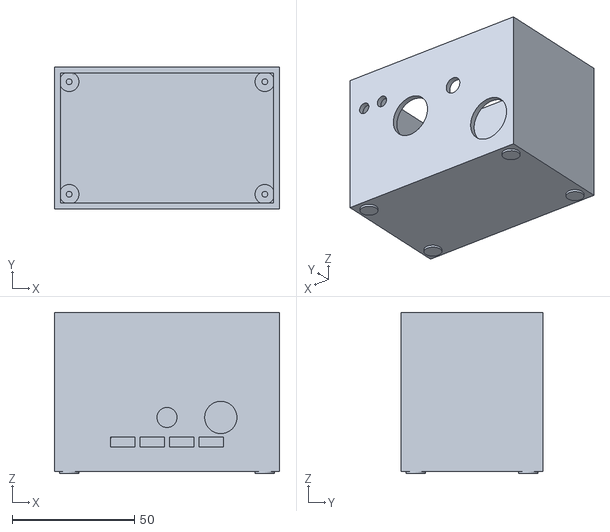
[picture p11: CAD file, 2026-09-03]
caixa-3d/print/v1/corpo_cor1.stl
92.0 x 58.0 x 66.0

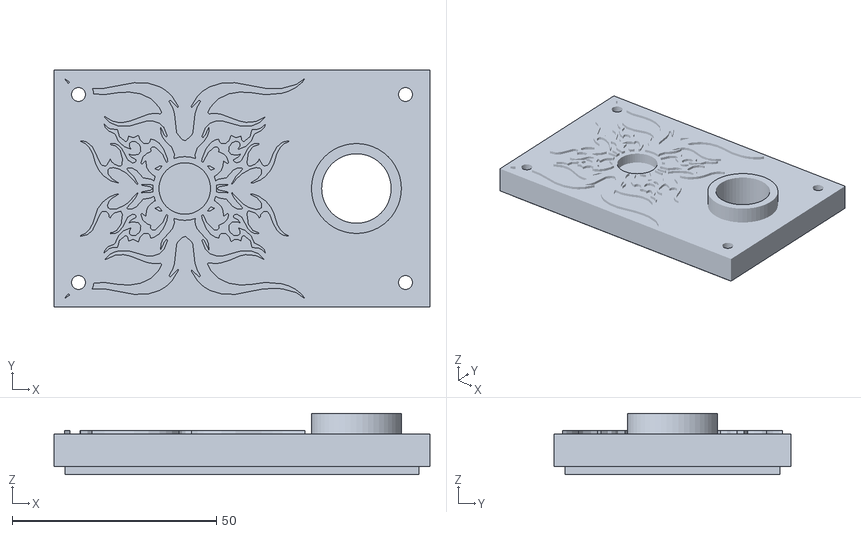
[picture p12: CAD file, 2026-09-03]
caixa-3d/stl/box_lid.stl
92.0 x 58.0 x 15.0

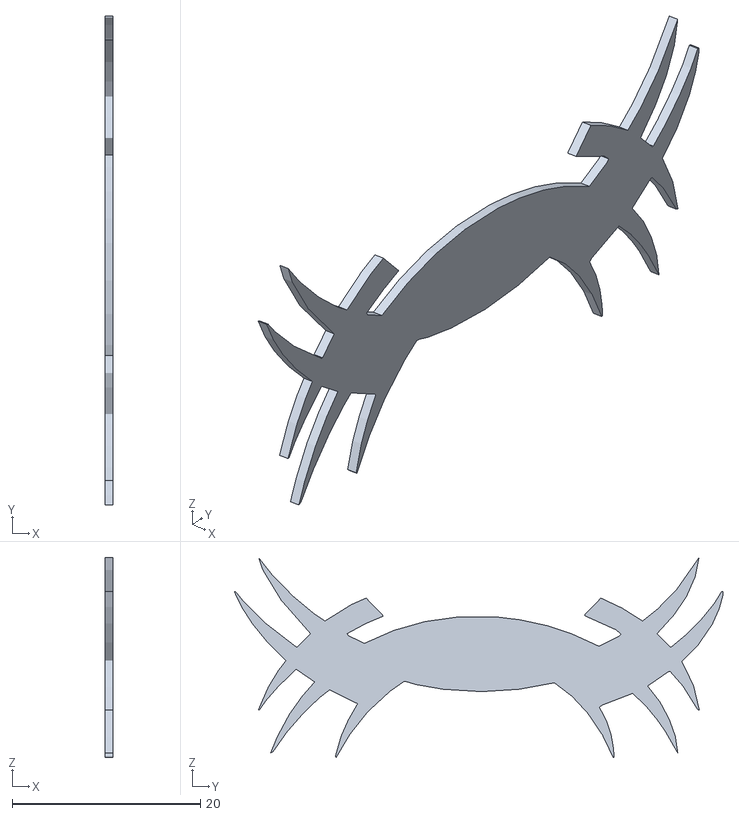
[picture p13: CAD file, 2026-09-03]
caixa-3d/stl/previews/part_left.stl
0.8 x 52.0 x 21.3

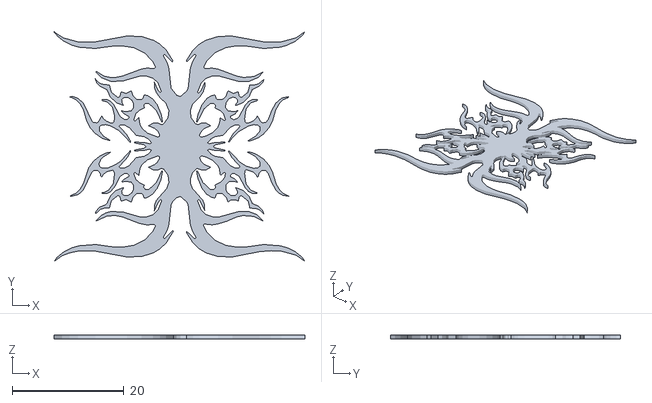
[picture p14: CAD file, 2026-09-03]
caixa-3d/decals/tribal_2_emboss.stl
45.0 x 41.2 x 0.8

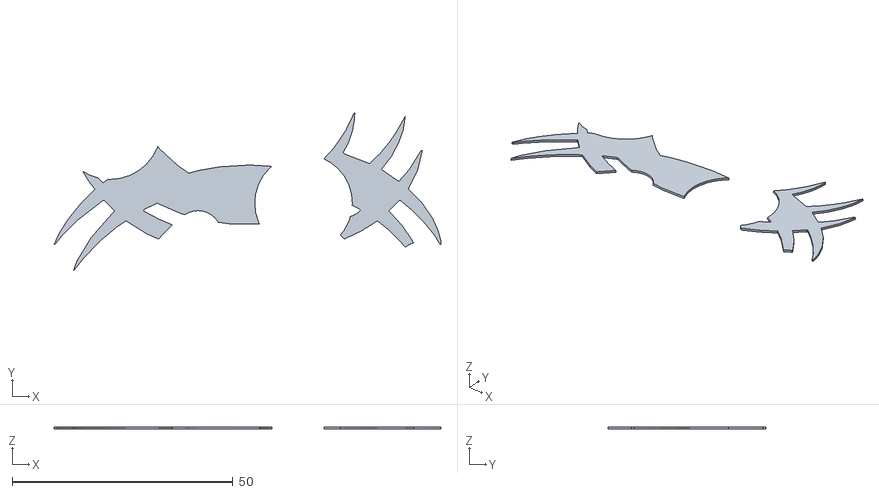
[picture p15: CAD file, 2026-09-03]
caixa-3d/print/v1-cavas/decal_frente.stl
87.7 x 35.9 x 0.5

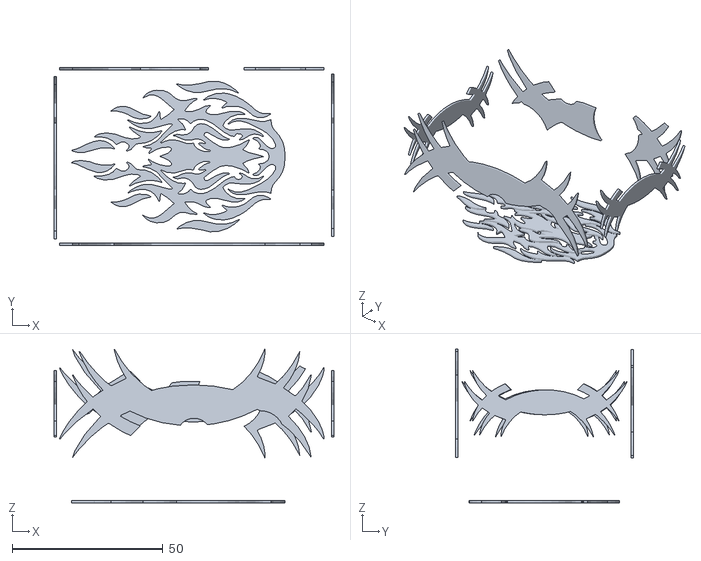
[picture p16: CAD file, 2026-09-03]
caixa-3d/print/v1/corpo_cor2.stl
93.0 x 59.0 x 51.0

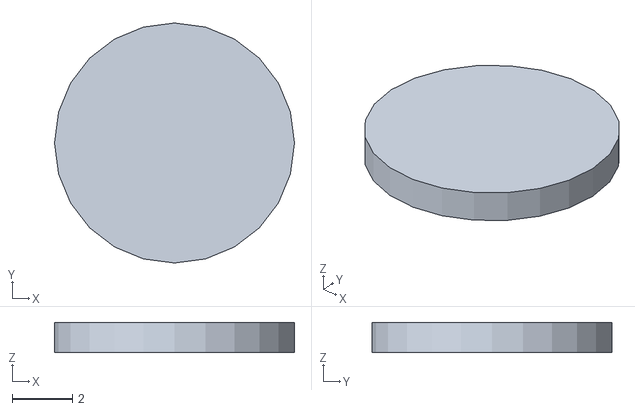
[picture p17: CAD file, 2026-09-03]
caixa-3d/stl/previews/part_pad0.stl
8.00 x 8.00 x 1.00

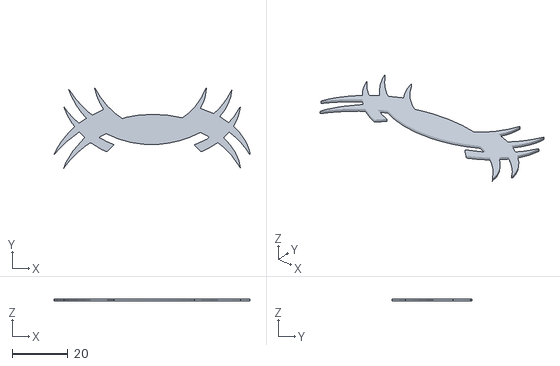
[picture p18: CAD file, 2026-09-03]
caixa-3d/decals/tribal_1_emboss.stl
70.0 x 28.6 x 0.8

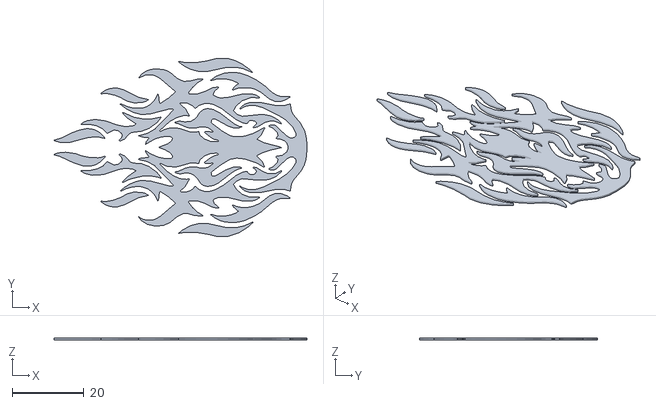
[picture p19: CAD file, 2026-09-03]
caixa-3d/print/v1-cavas/decal_base.stl
70.6 x 49.8 x 0.5

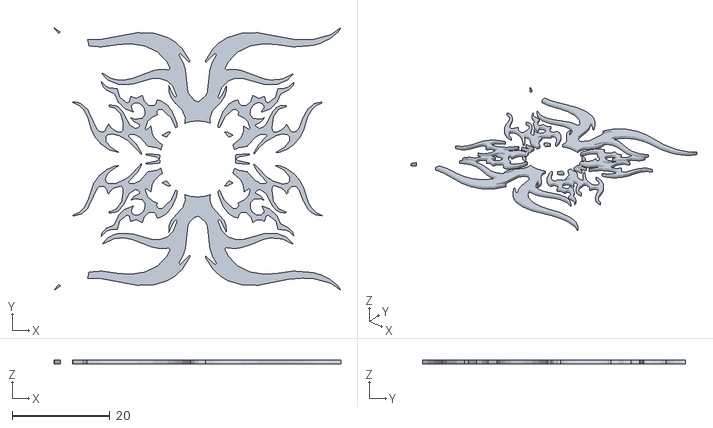
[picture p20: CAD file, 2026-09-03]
caixa-3d/print/v1/tampa_cor2.stl
58.8 x 53.9 x 0.8

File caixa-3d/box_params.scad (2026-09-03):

// box_params.scad — Indutor Dynavap v3.2
// Espelha maquetes/dimensions.json (corpo 92×58×65 + tampa 8).
// Coordenadas OpenSCAD (impressão): X=largura, Y=profundidade (frente=+Y), Z=altura.

BOX_W = 92;
BOX_D = 58;
BOX_H = 65;
WALL  = 2.5;
FLOOR = 2.5;
LID_H = 8;

// Câmara (tubo) — offset à direita do centro
TUBE_X      = 28;
TUBE_HOLE_R = 8.5;   // Ø17 clearance para OD16 + folga
COLLAR_OD   = 22;
COLLAR_ID   = 17;
COLLAR_H    = 5;

// Ímã de descanso — centro da área livre da tampa (sem o bocal/collarinho)
// Área livre X: (-BOX_W/2+2) … (TUBE_X-COLLAR_OD/2-1.5) → centro ≈ -14
MAGNET_X    = -14;
MAGNET_Y    = 0;
MAGNET_D    = 12;    // disco alvo Ø12
MAGNET_H    = 3;     // espessura 3 mm (use 6 p/ boss extra)
MAGNET_CLR_D = 0.6;  // folga diametral total → pocket Ø12.6
MAGNET_CLR_H = 0.2;  // folga profundidade → 3.2 mm
POCKET_D    = MAGNET_D + MAGNET_CLR_D;
POCKET_H    = MAGNET_H + MAGNET_CLR_H;
// Se MAGNET_H > LID_H - 4, gera boss local
MAGNET_BOSS = (MAGNET_H > 3) ? (MAGNET_H - 3) : 0;

// Ventilação traseira (−Y)
VENT_N = 4;
VENT_W = 10;
VENT_H = 4;
VENT_Z = 12;         // altura do centro do slot a partir do piso interno

// Painel frontal (+Y) — Y absolutos do JSON → Z na peça
// A7 KCD1-106N redonda Ø20; A5 WH148 bushing Ø7.6; A6 Ø19.2; A9 Ø5.2
ROCK_X = -32; ROCK_Z = 18; ROCK_R = 10.1;  // Ø20.2
POT_X  = -12; POT_Z  = 42; POT_R  = 3.8;   // Ø7.6
BTN_X  =  12; BTN_Z  = 35; BTN_R  = 9.6;   // Ø19.2
LED1_X =  28; LED1_Z = 48; LED_R  = 2.6;   // Ø5.2
LED2_X =  38; LED2_Z = 48;

// Jack DC-022 Ø8.2 + porta-fusível 5×20 painel Ø13.2 (traseira −Y)
JACK_X = 0;  JACK_Z = 22; JACK_R = 4.1;
FUSE_X = 22; FUSE_Z = 22; FUSE_R = 6.6;

// Parafusos tampa M3 (furos 3.4 mm)
SCREW_R = 1.7;
SCREW_INSET = 6;     // margem da borda até centro do furo
LIP_H = 2;           // ressalto interno da tampa (encaixe)
LIP_CLR = 0.3;       // folga do lip vs interno

// ── Alto relevo tribal (decals/*.stl) ──
EMBOSS_H      = 0.8;   // altura do relevo (mm) — camada extra p/ filament claro
EMBOSS_MARGIN = 2.0;   // margem mínima das arestas (preencher área livre)
BOTTOM_PAD_H  = 1.0;   // pads nos cantos (assento estável)
KEEPOUT_CLR   = 1.5;   // folga ao redor de furos

// Larguras alvo dos STL gerados (ver vectorize_decals.py)
DECAL1_W = 70;   // laterais — escala por face
DECAL2_W = 36;   // tampa — área livre (sem bocal); ímã no centro
DECAL3_W = 42;   // base — cabe em 92×58 com margem

$fn = 48;

function screw_xy() = [
  [ BOX_W/2 - SCREW_INSET,  BOX_D/2 - SCREW_INSET],
  [-BOX_W/2 + SCREW_INSET,  BOX_D/2 - SCREW_INSET],
  [ BOX_W/2 - SCREW_INSET, -BOX_D/2 + SCREW_INSET],
  [-BOX_W/2 + SCREW_INSET, -BOX_D/2 + SCREW_INSET]
];

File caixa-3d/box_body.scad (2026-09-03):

// box_body.scad — Corpo oco (relevo tribal aplicado depois em assemble_embossed.py)
include <box_params.scad>

module body_shell() {
  difference() {
    cube([BOX_W, BOX_D, BOX_H], center = true);
    translate([0, 0, FLOOR/2 + 0.01])
      cube([BOX_W - 2*WALL, BOX_D - 2*WALL, BOX_H - FLOOR + 0.2], center = true);
  }
}

module front_holes() {
  z0 = -BOX_H/2;
  translate([ROCK_X, BOX_D/2, z0 + ROCK_Z])
    rotate([90, 0, 0]) cylinder(h = WALL + 4, r = ROCK_R, center = true);
  translate([BTN_X, BOX_D/2, z0 + BTN_Z])
    rotate([90, 0, 0]) cylinder(h = WALL + 4, r = BTN_R, center = true);
  translate([POT_X, BOX_D/2, z0 + POT_Z])
    rotate([90, 0, 0]) cylinder(h = WALL + 4, r = POT_R, center = true);
  translate([LED1_X, BOX_D/2, z0 + LED1_Z])
    rotate([90, 0, 0]) cylinder(h = WALL + 4, r = LED_R, center = true);
  translate([LED2_X, BOX_D/2, z0 + LED2_Z])
    rotate([90, 0, 0]) cylinder(h = WALL + 4, r = LED_R, center = true);
}

module rear_features() {
  z0 = -BOX_H/2;
  translate([JACK_X, -BOX_D/2, z0 + JACK_Z])
    rotate([90, 0, 0]) cylinder(h = WALL + 4, r = JACK_R, center = true);
  translate([FUSE_X, -BOX_D/2, z0 + FUSE_Z])
    rotate([90, 0, 0]) cylinder(h = WALL + 4, r = FUSE_R, center = true);
  span = (VENT_N - 1) * (VENT_W + 2);
  for (i = [0 : VENT_N - 1]) {
    x = -span/2 + i * (VENT_W + 2);
    translate([x, -BOX_D/2, z0 + VENT_Z])
      cube([VENT_W, WALL + 4, VENT_H], center = true);
  }
}

module top_tube_clearance() {
  translate([TUBE_X, 0, BOX_H/2])
    cylinder(h = WALL + 6, r = TUBE_HOLE_R, center = true);
}

module screw_posts() {
  post_r = 4;
  post_h = 8;
  for (p = screw_xy()) {
    translate([p[0], p[1], -BOX_H/2 + FLOOR])
      difference() {
        cylinder(h = post_h, r = post_r);
        translate([0, 0, -0.1])
          cylinder(h = post_h + 0.2, r = 1.2);
      }
  }
}

module box_body() {
  difference() {
    union() {
      body_shell();
      screw_posts();
    }
    front_holes();
    rear_features();
    top_tube_clearance();
  }
}

box_body();

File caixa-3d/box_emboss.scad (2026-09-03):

// box_emboss.scad — Alto relevo tribal (import STL dos decals)
include <box_params.scad>

DECAL1_FILE = "decals/tribal_1_emboss.stl";
DECAL2_FILE = "decals/tribal_2_emboss.stl";
DECAL3_FILE = "decals/tribal_3_emboss.stl";

DECAL1_NATIVE_W = 70.0;
DECAL1_NATIVE_H = 28.5;
DECAL2_NATIVE_W = 45.0;
DECAL2_NATIVE_H = 41.3;
DECAL3_NATIVE_W = 50.0;
DECAL3_NATIVE_H = 80.6;

module emboss_scaled(file, native_w, native_h, max_w, max_h) {
  s = min(max_w / native_w, max_h / native_h);
  scale([s, s, 1])
    import(file, convexity = 12);
}

module front_keepouts() {
  z0 = -BOX_H/2;
  translate([ROCK_X, BOX_D/2, z0 + ROCK_Z])
    rotate([90, 0, 0]) cylinder(h = WALL + 8, r = ROCK_R + KEEPOUT_CLR, center = true);
  translate([BTN_X, BOX_D/2, z0 + BTN_Z])
    rotate([90, 0, 0]) cylinder(h = WALL + 8, r = BTN_R + KEEPOUT_CLR, center = true);
  translate([POT_X, BOX_D/2, z0 + POT_Z])
    rotate([90, 0, 0]) cylinder(h = WALL + 8, r = POT_R + KEEPOUT_CLR, center = true);
  translate([LED1_X, BOX_D/2, z0 + LED1_Z])
    rotate([90, 0, 0]) cylinder(h = WALL + 8, r = LED_R + KEEPOUT_CLR, center = true);
  translate([LED2_X, BOX_D/2, z0 + LED2_Z])
    rotate([90, 0, 0]) cylinder(h = WALL + 8, r = LED_R + KEEPOUT_CLR, center = true);
}

module rear_keepouts() {
  z0 = -BOX_H/2;
  translate([JACK_X, -BOX_D/2, z0 + JACK_Z])
    rotate([90, 0, 0]) cylinder(h = WALL + 8, r = JACK_R + KEEPOUT_CLR, center = true);
  translate([FUSE_X, -BOX_D/2, z0 + FUSE_Z])
    rotate([90, 0, 0]) cylinder(h = WALL + 8, r = FUSE_R + KEEPOUT_CLR, center = true);
  span = (VENT_N - 1) * (VENT_W + 2);
  for (i = [0 : VENT_N - 1]) {
    x = -span/2 + i * (VENT_W + 2);
    translate([x, -BOX_D/2, z0 + VENT_Z])
      cube([VENT_W + KEEPOUT_CLR, WALL + 8, VENT_H + KEEPOUT_CLR], center = true);
  }
}

// Frente (+Y): STL Z → +Y; STL X → X; STL Y → Z
module emboss_front() {
  mw = BOX_W - 2*EMBOSS_MARGIN;
  mh = BOX_H - 2*EMBOSS_MARGIN;
  difference() {
    translate([0, BOX_D/2, 0])
      rotate([-90, 0, 0])
        emboss_scaled(DECAL1_FILE, DECAL1_NATIVE_W, DECAL1_NATIVE_H, mw, mh);
    front_keepouts();
  }
}

// Trás (−Y): STL Z → −Y
module emboss_rear() {
  mw = BOX_W - 2*EMBOSS_MARGIN;
  mh = BOX_H - 2*EMBOSS_MARGIN;
  difference() {
    translate([0, -BOX_D/2, 0])
      rotate([90, 0, 0])
        emboss_scaled(DECAL1_FILE, DECAL1_NATIVE_W, DECAL1_NATIVE_H, mw, mh);
    rear_keepouts();
  }
}

// Esquerda (−X): STL Z → −X; largura do tribal ao longo de Y
module emboss_left() {
  mw = BOX_D - 2*EMBOSS_MARGIN;
  mh = BOX_H - 2*EMBOSS_MARGIN;
  translate([-BOX_W/2, 0, 0])
    rotate([0, -90, 0])
      rotate([0, 0, 90])
        emboss_scaled(DECAL1_FILE, DECAL1_NATIVE_W, DECAL1_NATIVE_H, mw, mh);
}

// Direita (+X): STL Z → +X
module emboss_right() {
  mw = BOX_D - 2*EMBOSS_MARGIN;
  mh = BOX_H - 2*EMBOSS_MARGIN;
  translate([BOX_W/2, 0, 0])
    rotate([0, 90, 0])
      rotate([0, 0, -90])
        emboss_scaled(DECAL1_FILE, DECAL1_NATIVE_W, DECAL1_NATIVE_H, mw, mh);
}

// Base (−Z): eixo longo // BOX_W (Rz 90); margem 4 mm
module emboss_bottom() {
  mw = BOX_D - 2*4;  // nativo W → profundidade após Rz90
  md = BOX_W - 2*4;  // nativo H → largura após Rz90
  translate([0, 0, -BOX_H/2])
    rotate([180, 0, 0])
      rotate([0, 0, 90])
        emboss_scaled(DECAL3_FILE, DECAL3_NATIVE_W, DECAL3_NATIVE_H, mw, md);

  for (p = screw_xy()) {
    translate([p[0], p[1], -BOX_H/2 - BOTTOM_PAD_H])
      cylinder(h = BOTTOM_PAD_H, r = 4);
  }
}

// Tampa (+Z): arte centrada no pocket do ímã (escala máx. sem recortar cantos)
module emboss_lid_top() {
  free_l = -BOX_W/2 + EMBOSS_MARGIN;
  free_r = TUBE_X - COLLAR_OD/2 - KEEPOUT_CLR;
  mw = free_r - free_l;
  md = BOX_D - 2*EMBOSS_MARGIN;
  difference() {
    translate([MAGNET_X, MAGNET_Y, LID_H/2])
      emboss_scaled(DECAL2_FILE, DECAL2_NATIVE_W, DECAL2_NATIVE_H, mw, md);
    translate([MAGNET_X, MAGNET_Y, LID_H/2])
      cylinder(h = EMBOSS_H * 6, r = POCKET_D/2 + KEEPOUT_CLR, center = true);
    translate([TUBE_X, 0, LID_H/2])
      cylinder(h = EMBOSS_H * 6, r = COLLAR_OD/2 + KEEPOUT_CLR, center = true);
    for (p = screw_xy()) {
      translate([p[0], p[1], LID_H/2])
        cylinder(h = EMBOSS_H * 6, r = SCREW_R + 2, center = true);
    }
  }
}

module body_emboss_all() {
  emboss_front();
  emboss_rear();
  emboss_left();
  emboss_right();
  emboss_bottom();
}

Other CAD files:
caixa-3d/stl/box_lid_base.stl
caixa-3d/stl/previews/part_pad2.stl
caixa-3d/box_lid.scad
caixa-3d/print/v1-cavas/corpo_cava.stl
caixa-3d/print/v1-cavas/decais.stl
caixa-3d/print/v1-cavas/decal_dir.stl
caixa-3d/print/v1-cavas/decal_esq.stl
caixa-3d/print/v1-cavas/decal_tampa.stl
caixa-3d/print/v1-cavas/tampa_cava.stl
caixa-3d/stl/box_body.stl
caixa-3d/stl/box_body_base.stl
caixa-3d/stl/box_body_decal.stl
caixa-3d/stl/previews/part_bottom.stl
caixa-3d/stl/previews/part_front.stl
caixa-3d/stl/previews/part_pad1.stl
caixa-3d/stl/previews/part_pad3.stl
caixa-3d/stl/previews/part_rear.stl
caixa-3d/stl/previews/part_right.stl

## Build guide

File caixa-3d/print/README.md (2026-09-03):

# Packs de impressão v1 (fechada)

Mesma caixa 92×58×65. Escolha **uma** variante:

| Pasta | Variante |
|---|---|
| [`v1-lisa/`](v1-lisa/) | Caixa lisa (sem tribal) + pads |
| [`v1/`](v1/) | Relevo 0,8 mm, duas cores no Orca (AMS) |
| [`v1-cavas/`](v1-cavas/) | Cavas 0,6 mm + inserts 0,5 mm para colar |

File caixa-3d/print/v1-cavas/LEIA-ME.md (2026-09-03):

# Pack v1 — cavas + inserts (cola)

**v1 fechada (set/2026).** Variante de cola. A outra variante oficial é [`../v1/`](../v1/) (relevo AMS).

Aqui o tribal é **cava** na casca; os inserts saem deitados para colar.

| Arquivo | O quê |
|---|---|
| `corpo_cava.stl` | Corpo com cavas 0,6 mm + pads |
| `tampa_cava.stl` | Tampa com cava 0,6 mm |
| `decais.stl` | Os 6 inserts numa placa |
| `decal_frente.stl` … `decal_tampa.stl` | Inserts soltos (0,5 mm, folga XY) |

## Impressão

1. Corpo e tampa: PETG, piso no bed / tampa deitada, **sem** Assemble com os decais.
2. `decais.stl`: deitado, 0,5 mm = ~2–3 camadas 0,2 mm. Cor de contraste.
3. Cola cianoacrilato ou epóxi nas cavas. Lixar se o insert ficar alto.

Não misture com `print/v1` no mesmo Assemble.

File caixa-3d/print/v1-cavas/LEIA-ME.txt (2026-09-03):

Pack v1 — cavas + cola (paralelo ao relevo AMS em print\v1)

v1 fechada (set/2026).

corpo_cava.stl / tampa_cava.stl = casca com cava 0,6 mm
decais.stl = 6 inserts 0,5 mm deitados (ou decal_frente.stl etc.)

Imprima casca e inserts separado. Cole o tribal nas cavas.
NAO use Assemble com o pack print\v1.

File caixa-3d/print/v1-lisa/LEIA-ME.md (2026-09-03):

# Pack v1 — caixa lisa (sem tribal)

**v1 fechada (set/2026).** Casca sem relevo e sem cava. Pads 1 mm na base do corpo.

| Arquivo | O quê |
|---|---|
| `corpo_liso.stl` | Corpo + 4 pads |
| `tampa_lisa.stl` | Tampa (pocket ímã, collarinho, furos) |

PETG, 0,2 mm, 15–25 % infill. Corpo piso no bed; tampa face plana no bed.

Outras variantes: [`../v1/`](../v1/) (relevo AMS) · [`../v1-cavas/`](../v1-cavas/) (cola).

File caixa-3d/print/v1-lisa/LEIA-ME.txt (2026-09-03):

Pack v1 — caixa lisa (sem tribal)

corpo_liso.stl  = corpo + pads
tampa_lisa.stl  = tampa

PETG 0,2 mm. Sem Assemble.
Outras: print\v1 (relevo) e print\v1-cavas (cola).

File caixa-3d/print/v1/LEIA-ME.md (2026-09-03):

# Pack v1 — relevo AMS (duas cores)

**v1 fechada (set/2026).** Variante de relevo. A outra variante oficial é [`../v1-cavas/`](../v1-cavas/).

Não use os STL unidos `box_body.stl` / `box_lid.stl` se quiser duas cores.

| Arquivo | Filamento |
|---|---|
| `corpo_cor1.stl` | **1** PETG escuro — casca + pads |
| `corpo_cor2.stl` | **2** PETG claro — tribal |
| `tampa_cor1.stl` | **1** PETG escuro — casca |
| `tampa_cor2.stl` | **2** PETG claro — tribal |

## OrcaSlicer / Bambu X1 Carbon

1. Importar o par da peça (`*_cor1` + `*_cor2`).
2. Selecionar os dois → **Assemble**.
3. Casca → Filament 1; relevo → Filament 2.
4. PETG, camada **0,2 mm**, bico **0,4 mm**, infill 15–25 %, sem suportes.
5. Corpo: **piso no bed**. Tampa: **face plana no bed** (pocket, collarinho e relevo para cima).
6. Relevo 0,8 mm = 4 camadas de cor 2.

Guia completo: [../README.md](../README.md)

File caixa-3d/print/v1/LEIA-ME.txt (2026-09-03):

Pack v1 — relevo AMS (duas cores)

v1 fechada (set/2026). Outra variante oficial: print\v1-cavas
Nao use box_body.stl / box_lid.stl se quiser duas cores.

Arquivos
--------
corpo_cor1.stl   Filamento 1  PETG escuro — casca + pads
corpo_cor2.stl   Filamento 2  PETG claro  — tribal
tampa_cor1.stl   Filamento 1  PETG escuro — casca
tampa_cor2.stl   Filamento 2  PETG claro  — tribal

OrcaSlicer / Bambu X1 Carbon
----------------------------
1. Importar o par da peca (cor1 + cor2).
2. Selecionar os dois -> Assemble.
3. Casca -> Filament 1; relevo -> Filament 2.
4. PETG, camada 0,2 mm, bico 0,4 mm, infill 15-25 %, sem suportes.
5. Corpo: piso no bed.
   Tampa: face plana no bed (pocket, collarinho e relevo para cima).
6. Relevo 0,8 mm = 4 camadas de cor 2.

Guia completo: caixa-3d\README.md

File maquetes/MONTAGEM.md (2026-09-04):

# Montagem — indutor Dynavap v1

Guia passo a passo alinhado ao [visualizador 3D](viewer.html). Cada passo abre no viewer com `viewer.html?step=N`.

Referências: [BOM e fiação](../BOM_E_FIACAO.md) · [Afinação](../AFINACAO_E_SEGURANCA.md) · [Caixa 3D](../caixa-3d/README.md) · [Layout interno](LAYOUT_INTERNO.md)

**Maquete v1.1:** abra o viewer via servidor local (`python -m http.server` em `maquetes/`) para o `fetch` de [`dimensions.json`](dimensions.json).

---

## Antes de começar

- [ ] Imprimir **v1**: [lisa](../caixa-3d/print/v1-lisa/), [relevo AMS](../caixa-3d/print/v1/) **ou** [cavas](../caixa-3d/print/v1-cavas/) (PETG, 0,2 mm, 15–25 % infill) — [guia](../caixa-3d/README.md)
- [ ] Conferir furos do painel (gangorra Ø20,2 · pot Ø7,6 · botão Ø19,2 · LEDs Ø5,2 · jack Ø8,2 · fusível Ø13,2)
- [ ] Fonte **12 V 10 A** (não 6 A; fonte **fora** da caixa)
- [ ] Multímetro, ferro de solda, fio 16 AWG silicone

---

## Passo 1 — Caixa vazia

**Viewer:** [passo 1](viewer.html?step=1)

1. Imprima **uma** variante: lisa (`corpo_liso` + `tampa_lisa`), relevo AMS (`corpo_cor1/2` + `tampa_cor1/2`, Orca Assemble) **ou** cavas (`corpo_cava` + `tampa_cava` + `decais`, cola).
2. Confira furos do painel frontal (CAD `box_params.scad`):
   - **A7** gangorra redonda — furo **Ø20,2 mm**
   - **A5** pot B10K — furo **Ø7,6 mm**
   - **A6** botão 19 mm — furo **Ø19,2 mm**
   - **A9** LEDs — 2× **Ø5,2 mm**
   - Traseira **A15** jack DC-022 — **Ø8,2 mm** + **A8** porta-fusível 5×20 — **Ø13,2 mm**
3. Confira furo superior para tubo Ø ~16 mm (clearance Ø17).
4. **Não** feche hermético — as frestas traseiras são ventilação do ZVS.
5. A **fonte 12 V 10 A fica fora** da caixa; entra só pelo jack.

| Check | OK |
|---|---|
| Corpo sem warping | [ ] |
| Furos alinhados com componentes reais | [ ] |
| Tampa encaixa sem forçar | [ ] |

---

## Passo 2 — Trilha 12 V

**Viewer:** [passo 2](viewer.html?step=2) · Ative **Fiação 12V** no painel lateral.

Ordem no positivo (vermelho, 16 AWG):

```
Fonte + → Jack fêmea → Fusível 10A → Rocker → barra 12V_SW
```

1. Instale o **jack P4** na traseira (solda ou parafuso).
2. **Fusível 10A** + suporte 5×20 no painel traseiro (só o porta-fusível de painel — sem bloco interno duplicado).
3. **Rocker KCD1** no painel frontal — comuta o positivo geral.
4. Negativo (preto): barra comum GND para fonte, MOSFET, ZVS, Nano.

| Check | OK |
|---|---|
| Multímetro: 12 V estável após rocker (ZVS desligado) | [ ] |
| Polaridade do jack conferida | [ ] |
| Fusível 10 A instalado | [ ] |

---

## Passo 3 — ZVS + TMP36

**Viewer:** [passo 3](viewer.html?step=3)

1. Assente o **ZVS** (envelope ~55×37×20) no **piso**, centro aproximado **X=−10**, levemente à traseira — gap ≥3 mm das paredes, ≥2 mm do tubo (X=28).
2. TMP36 com pasta térmica na face do dissipador voltada aos **vents** (−Z).
3. Não encoste o dissipador no PETG.

| Check | OK |
|---|---|
| Gap ZVS↔parede ≥3 mm | [ ] |
| Fins alinhados ao fluxo dos vents | [ ] |
| Serial `Ts=` sobe com o ZVS ligado (passo firmware) | [ ] |

---

## Passo 4 — MOSFET

**Viewer:** [passo 4](viewer.html?step=4)

O **XY-MOS 15 A** comuta o positivo entre a barra 12 V e o ZVS.

| Borne | Liga em |
|---|---|
| V+ in | 12 V depois do fusível / rocker |
| V− in | GND |
| V+ out | ZVS + |
| TRIG | Nano D3 (passo 5) |
| V− out | GND (ou ZVS −) |

1. Monte o MOSFET **acima** do ZVS (standoffs ≥2 mm) — não ao lado no piso (Z interno apertado).
2. Fios de potência **curtos**.

| Check | OK |
|---|---|
| Standoff ≥2 mm sobre o ZVS | [ ] |
| Sem curto mecânico com o Nano | [ ] |

---

## Passo 5 — Arduino Nano

**Viewer:** [passo 5](viewer.html?step=5)

1. Nano **acima** do MOSFET/ZVS (centro ~Y=46), isolado da parede.
2. D3 → TRIG do MOSFET; sensor TMP36; botão / pot / LEDs nos furos do painel.
3. USB: use jumpers ou grave antes de fechar — não há cutout USB na caixa.

| Check | OK |
|---|---|
| Gap Nano↔tampa ≥3 mm | [ ] |
| Não toca dissipador do ZVS | [ ] |

---

## Passo 6 — Painel frontal

**Viewer:** [passo 6](viewer.html?step=6)

Instale botão Ø19,2, pot bushing Ø7,6, LEDs Ø5,2 nos furos **já impressos** (posições congeladas). LED D6 aponta para o tubo.

---

## Passo 7 — Câmara (cama + tubo + bobina)

**Viewer:** [passo 7](viewer.html?step=7)

1. **Cama cerâmica Ø24×8** no piso sob o eixo X=28 (não torre alta).
2. Tubo ensaio Ø16 cortado ~42 mm, fundo fechado, assentado na cama.
3. Bobina **ID ≥16 / OD ~22** em volta do vidro (não apertar a ponto de rachar).
4. O-ring 15×3 no collarinho da tampa.

| Check | OK |
|---|---|
| Fundo do tubo na cama | [ ] |
| Bobina não raspa a parede | [ ] |

---

## Passo 8 — Checagem térmica / ventilação

**Viewer:** [passo 8](viewer.html?step=8)

Vents traseiros livres; tampa **não** hermética. Ver [LAYOUT_INTERNO.md](LAYOUT_INTERNO.md).

---

## Passo 9 — Tampa + ímã

**Viewer:** [passo 9](viewer.html?step=9)

Collarinho Ø22; ímã Ø12×3 colado no pocket **X=−14**. Parafusos M3 nos cantos.

---

## Passo 10 — Pronto

**Viewer:** [passo 10](viewer.html?step=10)

1. Cap no fundo de vidro; M7 ~92 mm; descanso no ímã.
2. Rocker ON → botão → alvo clique **5–8 s** (~60–70 W).
3. Confirme timeout 60 s e corte TMP36 60 °C — [AFINACAO_E_SEGURANCA.md](../AFINACAO_E_SEGURANCA.md).

### Pinos Nano (resumo)

| Pino | Função |
|---|---|
| D2 | Botão → GND (pull-up) |
| D3 | TRIG MOSFET |
| D5 / D6 | LED status / câmara (+ 470 Ω) |
| A0 | Pot 10k |
| A1 | TMP36 Vout |
| VIN / GND | 12 V após rocker / barra comum |

| Check | OK |
|---|---|
| Clique em 5–8 s | [ ] |
| Timeout e corte térmico OK | [ ] |
| Ventilação livre ao fechar | [ ] |

---

## Ordem elétrica resumida

```mermaid
flowchart TD
  P1[Passo1_Caixa] --> P2[Passo2_Jack_fusivel_rocker]
  P2 --> P3[Passo3_ZVS_TMP36]
  P3 --> P4[Passo4_MOSFET]
  P4 --> P5[Passo5_Nano]
  P5 --> P6[Passo6_Painel]
  P6 --> P7[Passo7_Camara]
  P7 --> P8[Passo8_Termica]
  P8 --> P9[Passo9_Tampa]
  P9 --> P10[Passo10_Afinacao]
```

Layout interno: [LAYOUT_INTERNO.md](LAYOUT_INTERNO.md). Pós-montagem: [MELHORIAS.md](MELHORIAS.md).

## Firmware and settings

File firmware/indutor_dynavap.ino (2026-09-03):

/*
 * Indutor DIY para Dynavap — v1 desktop fechada (set/2026)
 *
 * Mesa 12 V 10 A na tomada. Caixa v1: print/v1-lisa, print/v1 (relevo) ou print/v1-cavas (cola).
 *
 * Botão pressionado = aquece. Soltou = para.
 * Timeout 60 s (YLL 3.0) mesmo com o botão preso.
 * Potenciómetro = duty LENTO (120–500 ms). Não é analogWrite no ZVS.
 * TMP36 no dissipador do ZVS: bloqueia em >= 60 °C, libera abaixo de 55 °C.
 *
 * Pinos (Nano): ver BOM_E_FIACAO.md
 *   D2 botão (pull-up, ativo LOW)
 *   D3 TRIG MOSFET
 *   D5 LED status
 *   D6 LED câmara
 *   A0 pot 10k
 *   A1 TMP36
 *
 * Se o MOSFET ligar o ZVS com TRIG em GND, mude MOSFET_ACTIVE_HIGH para 0.
 */

const uint8_t PIN_BUTTON = 2;
const uint8_t PIN_MOSFET = 3;
const uint8_t PIN_LED_STATUS = 5;
const uint8_t PIN_LED_CHAMBER = 6;
const uint8_t PIN_POT = A0;
const uint8_t PIN_TMP36 = A1;

const uint8_t MOSFET_ACTIVE_HIGH = 1;

const unsigned long TIMEOUT_MS = 60000UL;
const unsigned long DEBOUNCE_MS = 30UL;
const unsigned long PULSE_PERIOD_MS = 500UL;
const unsigned long PULSE_ON_MIN_MS = 120UL;  // ZVS precisa arrancar a oscilação
const int FULL_POWER_ADC = 48;                // ~5% do curso: potência cheia
const int TEMP_CUTOFF_C = 60;
const int TEMP_REARM_C = 55;
const int TEMP_VALID_MIN_C = -10;
const int TEMP_VALID_MAX_C = 100;
const unsigned long SERIAL_MS = 500UL;

bool thermalLock = false;
bool timedOut = false;
unsigned long heatStartMs = 0;
unsigned long lastButtonChangeMs = 0;
bool buttonStable = false;              // true = pressionado (ativo)
bool buttonRawPrev = false;
unsigned long lastSerialMs = 0;

void mosfetWrite(bool on) {
  uint8_t level;
  if (MOSFET_ACTIVE_HIGH) {
    level = on ? HIGH : LOW;
  } else {
    level = on ? LOW : HIGH;
  }
  digitalWrite(PIN_MOSFET, level);
}

bool readButtonPressed() {
  bool raw = (digitalRead(PIN_BUTTON) == LOW);
  unsigned long now = millis();
  if (raw != buttonRawPrev) {
    lastButtonChangeMs = now;
    buttonRawPrev = raw;
  }
  if ((now - lastButtonChangeMs) >= DEBOUNCE_MS) {
    buttonStable = raw;
  }
  return buttonStable;
}

int readTempC() {
  int adc = analogRead(PIN_TMP36);
  float volts = adc * (5.0f / 1023.0f);
  return (int)((volts - 0.5f) * 100.0f);
}

bool tempSensorValid(int tempC) {
  return (tempC >= TEMP_VALID_MIN_C && tempC <= TEMP_VALID_MAX_C);
}

bool heatWantedThisCycle(int potAdc, unsigned long now) {
  if (potAdc <= FULL_POWER_ADC) {
    return true;
  }
  unsigned long onMs = map(
      (long)potAdc,
      FULL_POWER_ADC,
      1023L,
      (long)PULSE_PERIOD_MS,
      (long)PULSE_ON_MIN_MS);
  if (onMs < PULSE_ON_MIN_MS) {
    onMs = PULSE_ON_MIN_MS;
  }
  if (onMs > PULSE_PERIOD_MS) {
    onMs = PULSE_PERIOD_MS;
  }
  return ((now % PULSE_PERIOD_MS) < onMs);
}

void setup() {
  pinMode(PIN_BUTTON, INPUT_PULLUP);
  pinMode(PIN_MOSFET, OUTPUT);
  pinMode(PIN_LED_STATUS, OUTPUT);
  pinMode(PIN_LED_CHAMBER, OUTPUT);
  mosfetWrite(false);
  digitalWrite(PIN_LED_STATUS, LOW);
  digitalWrite(PIN_LED_CHAMBER, LOW);
  Serial.begin(9600);
}

void loop() {
  unsigned long now = millis();
  bool pressed = readButtonPressed();
  int potAdc = analogRead(PIN_POT);
  int tempC = readTempC();

  if (tempSensorValid(tempC)) {
    if (tempC >= TEMP_CUTOFF_C) {
      thermalLock = true;
    } else if (tempC <= TEMP_REARM_C) {
      thermalLock = false;
    }
  } else {
    thermalLock = false;
  }

  if (!pressed) {
    timedOut = false;
    heatStartMs = 0;
  } else {
    if (heatStartMs == 0) {
      heatStartMs = now;
    }
    if ((now - heatStartMs) >= TIMEOUT_MS) {
      timedOut = true;
    }
  }

  bool allowHeat = pressed && !thermalLock && !timedOut;
  bool zvsOn = allowHeat && heatWantedThisCycle(potAdc, now);

  mosfetWrite(zvsOn);
  digitalWrite(PIN_LED_CHAMBER, zvsOn ? HIGH : LOW);

  if (thermalLock) {
    digitalWrite(PIN_LED_STATUS, ((now / 120) % 2) ? HIGH : LOW);
  } else if (timedOut) {
    digitalWrite(PIN_LED_STATUS, ((now / 400) % 2) ? HIGH : LOW);
  } else if (zvsOn) {
    digitalWrite(PIN_LED_STATUS, HIGH);
  } else if (allowHeat) {
    digitalWrite(PIN_LED_STATUS, ((now / 80) % 2) ? HIGH : LOW);
  } else {
    digitalWrite(PIN_LED_STATUS, LOW);
  }

  if ((now - lastSerialMs) >= SERIAL_MS) {
    lastSerialMs = now;
    Serial.print(F("btn="));
    Serial.print(pressed ? 1 : 0);
    Serial.print(F(" pot="));
    Serial.print(potAdc);
    Serial.print(F(" T="));
    Serial.print(tempC);
    Serial.print(F(" Ts="));
    Serial.print(tempSensorValid(tempC) ? 1 : 0);
    Serial.print(F(" lock="));
    Serial.print(thermalLock ? 1 : 0);
    Serial.print(F(" to="));
    Serial.print(timedOut ? 1 : 0);
    Serial.print(F(" zvs="));
    Serial.println(zvsOn ? 1 : 0);
  }
}

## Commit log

2026-09-03 Release v1: packs lisa, relevo e cavas, CAD, docs e firmware.
    Publica a v1 desktop completa com STLs oficiais, maquetes e listas de compra.
    [box_assembly_preview.stl, box_body.scad, box_body.stl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]
2026-09-04 Maquete v1.1: layout interno preciso na caixa congelada.
    Reorganiza ZVS/MOSFET/Nano sem colisoes, alinha o viewer ao dimensions.json e documenta clearances; furos/STL da caixa intactos.
